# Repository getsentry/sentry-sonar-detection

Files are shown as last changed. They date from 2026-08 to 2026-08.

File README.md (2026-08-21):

<p align="center">
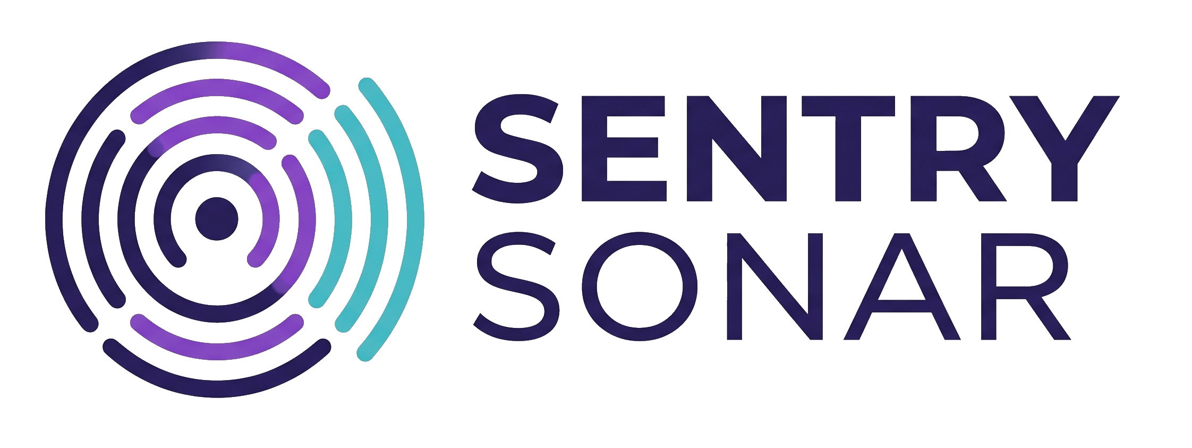
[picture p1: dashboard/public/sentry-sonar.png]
Sentry Sonar
  
</p>

# Sentry Sonar

Real-time meeting-room availability, sensed by radar and shown right on the door.

## What it does

A 24GHz radar sensor in each room detects human presence — *that* a person is
there, never *who* (no cameras, no microphones) — and reports to a Cloudflare
Workers API. Two consumers read that data:

- **E-ink door displays** show **FREE / OCCUPIED** at a glance. Battery-powered,
  they deep-sleep and poll during office hours, running ~1–2 weeks per charge.
- **A web dashboard** gives a live overview of every room, plus how they're used
  over time (utilization, busy hours).

**The outcome:** walk down the hall and see which rooms are free without opening a
calendar or a booking app — and see room-usage trends on the dashboard. Privacy by
design: radar only knows presence, not identity.

## Architecture

```
 Sensor node (Freenove ESP32 + LD2410C radar) ──POST /events──►  Cloudflare
                                                                  Worker (Hono)
 Display node (Waveshare e-paper)  ──GET /rooms/:id──►            + D1
 Dashboard (React SPA)             ──GET /rooms─────►             + static assets
```

Two nodes per room: a mains-powered **sensor node** that senses continuously, and a
battery **display node** that deep-sleeps and polls during office hours. A single
Cloudflare Worker (Hono) on D1 holds current room state plus an append-only event
log **and** serves the dashboard (React SPA) as static assets — same origin, one URL.

## Repo layout

```
firmware/sensor-node/    Freenove + LD2410C radar (PlatformIO)
firmware/display-node/   Waveshare e-paper (GxEPD2 + deep sleep)
api/                     Cloudflare Worker (Hono) + D1 migrations
dashboard/               React SPA (Vite) — served by the Worker as static assets
```

## Docs

- **[SETUP.md](./SETUP.md)** — step-by-step to stand up your own copy end to end
  (Cloudflare backend, dashboard, device tokens, firmware).
- **[PLAN.md](./PLAN.md)** — design, data model, API surface, and the decisions
  behind them.
- **[PRODUCTIONIZING.md](./PRODUCTIONIZING.md)** — current state and what a full
  office-wide rollout would take (IoT Wi-Fi, display power, more pairs, Sentry-
  hosted dashboard, and the operational gaps in between).
- **[api/README.md](./api/README.md)** — API endpoints, deploy & operate, tokens.
- **[firmware/README.md](./firmware/README.md)** — flashing sensors & displays,
  board pinouts, and the battery/power gotchas.

## Status

Hackweek project — 4 rooms, 4 device kits, all provisioned and running.

- App — dashboard + API on one Worker:
  <https://sentry-sonar-api.francesconovy.workers.dev> (the dashboard is at the
  root path; its data only loads from an allowlisted office IP)

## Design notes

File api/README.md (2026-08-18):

# Sentry Sonar — API

Cloudflare Worker ([Hono](https://hono.dev/)) backed by [D1](https://developers.cloudflare.com/d1/).
It ingests presence heartbeats from the sensor nodes and serves room status to
the e-ink displays and the dashboard. See [`../PLAN.md`](../PLAN.md) for the
overall design.

**Deployed at:** <https://sentry-sonar-api.francesconovy.workers.dev>

## Endpoints

| Method | Path | Caller | Auth |
|---|---|---|---|
| `GET` | `/healthz` | anyone | none (health check) |
| `POST` | `/events` | sensor node | device token — **write**, that room |
| `GET` | `/rooms/:id` | display node | device token — **read**, that room |
| `GET` | `/rooms` | dashboard | office IP allowlist |
| `GET` | `/rooms/:id/stats` | dashboard | office IP allowlist |

This same Worker also **serves the dashboard SPA** as static assets (Workers Static
Assets): the API paths above are listed under `run_worker_first` in `wrangler.jsonc`
so they always reach the Worker, and every other path (`/`, `/room-details/:id`,
`/assets/*`, …) is served from the built dashboard, with an `index.html` SPA
fallback. Same origin, so no CORS.

A room's `status` is **derived**, not stored:

- `offline` — no heartbeat within 90s (`OFFLINE_AFTER_SECONDS`), or never seen.
- `in_use` — a recent heartbeat with `occupied: true`.
- `free` — a recent heartbeat with `occupied: false`.

### `GET /healthz` — health

(`/` serves the dashboard SPA, so the health check lives at `/healthz`.)

```console
$ curl https://sentry-sonar-api.francesconovy.workers.dev/healthz
{"service":"sentry-sonar-api","ok":true}
```

### `POST /events` — sensor heartbeat

Send every ~15s. The current room state is upserted; a row is appended to the
event log **only when the occupied state changes** (keeps history compact).

Headers: `Authorization: Bearer <write-token>`, `Content-Type: application/json`

Body:

| field | type | required | notes |
|---|---|---|---|
| `room_id` | string | yes | must match the token's room |
| `occupied` | boolean | yes | radar presence (LD2410C `OUT` pin) |

```console
$ curl -X POST https://sentry-sonar-api.francesconovy.workers.dev/events \
    -H "Authorization: Bearer $TOKEN" -H 'content-type: application/json' \
    -d '{"room_id":"urwald","occupied":true}'
{"ok":true,"room":{"id":"urwald","name":"Urwald","status":"in_use","occupied":true,"lastSeen":1786957010}}
```

Errors: `400` invalid body · `401` bad/missing token · `403` token not allowed
for that room, or a read-only token · `404` unknown room.

### `GET /rooms/:id` — single room (display node)

Tiny payload for the e-ink display. Auth: a **read** (or write) token for that room.

```console
$ curl https://sentry-sonar-api.francesconovy.workers.dev/rooms/urwald -H "Authorization: Bearer $TOKEN"
{"id":"urwald","name":"Urwald","status":"in_use","occupied":true,"lastSeen":1786957010}
```

### `GET /rooms` — all rooms (dashboard)

```console
$ curl https://sentry-sonar-api.francesconovy.workers.dev/rooms
{"now":1786957010,"rooms":[
  {"id":"makava-kingdom","name":"Makava Kingdom","status":"offline","occupied":false,"lastSeen":null},
  {"id":"servus","name":"Servus","status":"offline","occupied":false,"lastSeen":null},
  {"id":"urwald","name":"Urwald","status":"in_use","occupied":true,"lastSeen":1786957010},
  {"id":"oida","name":"Oida","status":"offline","occupied":false,"lastSeen":null}
]}
```

### `GET /rooms/:id/stats` — utilization

Fraction of **office hours** (Mon–Fri 08:00–18:00 Europe/Vienna) the room was
occupied, reconstructed from the event log — nights and weekends are excluded from
both `occupiedSeconds` and `totalSeconds`. Query: `hours` (default `24`, max `720`).

```console
$ curl "https://sentry-sonar-api.francesconovy.workers.dev/rooms/urwald/stats?hours=24"
{"room":"urwald","hours":24,"occupiedSeconds":5400,"totalSeconds":86400,"ratio":0.0625}
```

## Authentication

Two mechanisms for two very different callers (full rationale in `../PLAN.md`).

**Device tokens (sensor + display nodes).** Opaque bearer tokens of the form
`id.secret`, each scoped to one room and one action (`read`/`write`). Only the
SHA-256 hash of the secret is stored in the `api_tokens` table; a `write` token
also satisfies `read`. Sent as `Authorization: Bearer <token>`.

**Office IP allowlist (dashboard).** `GET /rooms` and `/rooms/:id/stats` are
gated by `OFFICE_IP_RANGES` (comma-separated CIDRs, IPv4 + IPv6) matched against
`CF-Connecting-IP`. Fails closed. It's supplied as a **binding**, not committed:
`.dev.vars` locally, a Worker **secret** (`wrangler secret put OFFICE_IP_RANGES`)
in production. For local dev you can instead set `ALLOW_INSECURE_LOCAL=true` in
`.dev.vars` to bypass the gate entirely (never set it in production).

## Local development

```sh
export VOLTA_FEATURE_PNPM=1              # once per shell (see SETUP.md)

cp .dev.vars.example .dev.vars           # local secrets + ALLOW_INSECURE_LOCAL
pnpm --filter api db:migrate:local       # create + migrate the local D1
pnpm --filter api dev                    # wrangler dev on http://localhost:8787
```

Mint a device token and register its hash in the local D1:

```sh
node scripts/mint-token.mjs urwald write
# prints the token once + a `wrangler d1 execute ... --local` INSERT to run
```

Then exercise it:

```sh
TOKEN=<the printed token>
curl -X POST localhost:8787/events -H "Authorization: Bearer $TOKEN" \
     -H 'content-type: application/json' -d '{"room_id":"urwald","occupied":true}'
curl localhost:8787/rooms          # ALLOW_INSECURE_LOCAL bypasses the IP gate
```

## Testing

Tests run inside the Workers runtime with a real local D1
([`@cloudflare/vitest-pool-workers`](https://developers.cloudflare.com/workers/testing/vitest-integration/)):
`ip`/`status` unit tests plus full route + auth + D1 integration tests.

```sh
pnpm --filter api test
```

## Deploy & operate

`wrangler` below is the api workspace's binary — run each from the repo root as
`pnpm --filter api exec wrangler …`, or drop the prefix from inside `api/`.
`deploy` needs `pnpm … run deploy` (it's a reserved pnpm subcommand).

**The Worker also serves the dashboard** (`assets` in `wrangler.jsonc` →
`../dashboard/dist`), so the SPA must be **built before deploying**. The easiest path
is the root **`pnpm run deploy`**, which runs `dashboard build` then `api run deploy`.

### First-time deploy

```sh
wrangler login                                   # authenticate (opens a browser)
wrangler d1 create sentry_sonar                  # → copy the printed database_id
# paste that id into api/wrangler.jsonc:  "database_id": "…"
pnpm --filter api db:migrate                     # apply schema + seed to the remote D1
pnpm run deploy                                       # (from repo root) build dashboard + deploy Worker
wrangler secret put OFFICE_IP_RANGES             # office CIDRs, e.g. 203.0.113.0/29
```

Deployed at <https://sentry-sonar-api.francesconovy.workers.dev>. First deploy on
a fresh account prompts you to pick a free `workers.dev` subdomain.

### Update the Worker (after code changes)

```sh
pnpm --filter api test && pnpm --filter api typecheck
pnpm run deploy   # (from repo root) rebuilds the dashboard + redeploys the Worker
```

(If you only changed the Worker and the dashboard `dist` is current, `pnpm --filter
api run deploy` alone works too.)

### Change a secret / the office allowlist

Secrets apply immediately (a new version, no redeploy). Re-run to change a value:

```sh
wrangler secret put OFFICE_IP_RANGES             # replace the office CIDRs
wrangler secret list
wrangler secret delete OFFICE_IP_RANGES
```

### Change the database schema

Add a **new** migration (never edit an already-applied one), then apply it
local → remote:

```sh
# create api/migrations/0003_<name>.sql
pnpm --filter api db:migrate:local               # apply to the local dev DB
pnpm --filter api db:migrate                     # apply to the remote DB
```

Ad-hoc SQL: `wrangler d1 execute sentry_sonar --remote --command "…"` (use
`--local` for the dev DB).

### Manage device tokens

```sh
# mint (prints the token once + an INSERT statement):
node scripts/mint-token.mjs urwald write
wrangler d1 execute sentry_sonar --remote --command "<the INSERT it printed>"

# list:
wrangler d1 execute sentry_sonar --remote \
  --command "SELECT id, room_id, scope, label, revoked FROM api_tokens;"

# revoke (takes effect immediately):
wrangler d1 execute sentry_sonar --remote \
  --command "UPDATE api_tokens SET revoked=1 WHERE id='ss_xxxx';"
```

### Logs & rollback

```sh
wrangler tail                                    # live request logs
wrangler deployments list                        # deployment history
wrangler rollback                                # revert to the previous version
```

## Layout

```
src/
  index.ts    routes
  auth.ts     device-token + office-IP middleware
  rooms.ts    DB helpers, derived status, heartbeat, utilization
  ip.ts       CIDR matching (IPv4 + IPv6)
  types.ts    shared row/view types
  env.ts      bindings + Hono generics
migrations/   D1 schema (0001) + room seed (0002)
scripts/      mint-token.mjs
test/         vitest (unit + integration)
```

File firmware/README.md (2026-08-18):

# Firmware

ESP32-S3 firmware for the two per-room nodes. Built and flashed with
[PlatformIO](https://platformio.org/) — **not** part of the pnpm workspace.

- **`sensor-node/`** — Freenove ESP32-S3-WROOM-1 + LD2410C radar. Mains-powered,
  always-on; POSTs presence heartbeats to the API (`POST /events`).
- **`display-node/`** — Waveshare ESP32-S3 1.54" e-paper. Battery-powered;
  deep-sleeps and polls `GET /rooms/:id` every 30–60s, redraws on change.

Each device is flashed with its own per-room bearer token and Wi-Fi credentials
(see [../PLAN.md → Authentication](../PLAN.md#authentication--authorization)). The
four rooms are `makava-kingdom`, `urwald`, `servus`, `oida` — use one of these as
the `--room` id below (they're seeded into D1 by the API migrations).

## Prerequisites

Install the PlatformIO **CLI** (`pio`). It is standalone — no VS Code required:

```sh
brew install platformio        # macOS
pio --version                  # confirm it's on PATH
```

First `pio run` for a new board downloads the ESP32 toolchain + Arduino
framework (~100 MB, a minute or two). That's a one-time cost; later builds are
fast.

## Sensor node — wiring

LD2410C 24GHz radar → ESP32-S3-WROOM-1, **3 jumper wires, no soldering, no level
shifter** (the LD2410C's IO is already 3.3V):

| LD2410C pad | → | ESP32-S3 pin |
|---|---|---|
| `VCC` (5V) | → | **5V** (USB-fed rail — *not* 3V3; the radar needs 5V) |
| `GND` | → | **GND** |
| `OUT` / `OT2` | → | **GPIO4** (silkscreen `4`; any free GPIO works if you change the sketch) |

Match the radar pads by their **silkscreen label**, not header position — the
order varies between batches. Mount the radar with its etched-antenna face
toward the room.

## Board & USB port

- **Board id:** `esp32-s3-devkitc-1` (correct generic id for the WROOM-1 module;
  already set in `sensor-node/platformio.ini`).
- The Freenove board has **two USB-C jacks**. Use the **UART** one (CH343
  bridge) — plain `Serial` output flows over it with no extra build flags. The
  other jack is the S3's *native* USB and only shows `Serial` if you compile in
  USB-CDC-on-boot, so it's the wrong choice for these sketches.
- Find the port: `pio device list`. The CH343 shows up as
  `/dev/cu.usbmodem*` with **Hardware ID `VID:PID=1A86:...`** (`1A86` = WCH).
  On macOS it enumerates driver-free.
- The two little buttons near the jacks are **BOOT** (=IO0) and **EN/RST** — not
  port labels.

## Flashing a sensor

`main.cpp` is the production firmware: read the LD2410C OUT pin → `POST /events`.
Each sensor needs a **unique room id + auth token**; the SSID defaults to
`Sentry-Guest` and you enter the WiFi password at flash time.

1. Mint a **write** token for the room and register it in the **remote
   (production) D1** (see [../api/README.md](../api/README.md#manage-device-tokens)):

   ```sh
   node ../../api/scripts/mint-token.mjs urwald write
   # It prints the token once, plus a `wrangler d1 execute … --local` line.
   # Run that line but change --local to --remote, so the hash lands in the
   # production DB the deployed Worker reads (otherwise the device gets 401).
   ```

2. Flash the board with that room + token (you'll be prompted for the WiFi
   password), from `firmware/sensor-node/`:

   ```sh
   ./flash-sensor.sh --room urwald --token 'ss_xxxx.secret' --monitor
   # --monitor opens the serial monitor after flashing so you can watch it boot.
   # options: --wifi-pass <pass>  --ssid <name>  --port /dev/cu.usbmodemXXXX
   ```

The script writes `src/config.gen.h` (gitignored — it holds the token),
compiles, and uploads. Repeat per sensor with its own room + token. Nothing
secret is committed.

## Flashing a display

`display-node/src/main.cpp` is the production firmware: wake from deep sleep,
`GET /rooms/:id`, redraw FREE / OCCUPIED only on change, sleep again. Each
display needs a **read** token for its room (a display can only read; it never
writes state).

1. Mint a **read** token for the room and register it in the **remote
   (production) D1** (see [../api/README.md](../api/README.md#manage-device-tokens)):

   ```sh
   node ../../api/scripts/mint-token.mjs makava-kingdom read
   # run the printed `wrangler d1 execute` line, changing --local to --remote
   ```

2. Flash the board with that room + token (you'll be prompted for the WiFi
   password), from `firmware/display-node/`:

   ```sh
   ./flash-display.sh --room makava-kingdom --token 'ss_xxxx.secret' --monitor
   # options: --wifi-pass <pass>  --ssid <name>  --port /dev/cu.usbmodemXXXX
   ```

   `--ssid` defaults to `Sentry-Guest`; set a per-machine default in
   `display.env` (copy `display.env.example`). The WiFi password is never stored.

Unlike the sensor's dual-jack Freenove, the display board has a **single
native-USB Type-C** port. Find it the same way — `pio device list` — but it
enumerates with **VID `303A:1001`** (Espressif), as `/dev/cu.usbmodem*`. Its two
side buttons are **PWR** and **BOOT** (the one with the "sun" icon).

> **Download mode is required to flash.** The production firmware deep-sleeps, so
> the board's USB port vanishes between wakes and the flasher can't open it. Put it
> in download mode first: unplug USB → hold **BOOT** (the "sun" side button) → plug
> USB back in → release BOOT. Then pass `--port /dev/cu.usbmodemXXXX` explicitly so
> auto-detect doesn't grab an unrelated serial device. See
> [Display board & power gotchas](#display-board--power-gotchas) for the why.

## Display power & polling strategy

The display runs on a small LiPo, so it does as little as possible. The Wi-Fi
wake is essentially the *entire* energy budget, so everything is tuned to minimize
how often the radio turns on.

- **Deep sleep between polls.** Each cycle is a fresh boot: wake → read battery →
  (in active hours) Wi-Fi + `GET /rooms/:id` → redraw **only if the frame
  changed** → deep sleep (~10 µA; e-ink holds its image with no power).
- **Office-hours only.** Polling runs **weekdays 08:00–18:00 local, every 60 s**.
  Nights and weekends the radio never turns on — the board shows an **OFF HOURS**
  message (not a stale FREE/OCCUPIED) and naps (waking at most every ~8 h just to
  re-check the battery) until the next weekday morning. Nobody's in the rooms then,
  so this roughly **triples** battery life.
- **Time without NTP.** The schedule needs a wall clock, which the ESP32 loses in
  deep sleep. Rather than an NTP round-trip, we read the `Date` header off every
  API response (free), track it across sleeps with the wake timer, and re-anchor on
  each daytime poll. Timezone/DST uses the Europe/Vienna POSIX rule.
- **Battery graphic, not a number.** The corner shows a rough fill level (redrawn
  only when the coarse level changes, not every poll); ≤10 % becomes a `!` alert;
  <3 % replaces the room status with a full-screen **RECHARGE ME** (radio kept
  off), so a dying panel never freezes on a misleading FREE/OCCUPIED.

**Expected life ≈ 9–10 days** on the 400 mAh cell (bank on ~1 week to be safe).
Weekday polling dominates, so the active-hours interval is the main lever: 2 min
→ ~2.5 weeks, 5 min → ~5 weeks, trading sign responsiveness for runtime. Tunables
are at the top of `src/main.cpp`: `POLL_SECONDS`, `ACTIVE_START_HOUR`,
`ACTIVE_END_HOUR`, `SKIP_WEEKENDS`.

## Display board & power gotchas

The display is a **Waveshare ESP32-S3-ePaper-1.54** (200×200 B/W, SSD1681 →
`GxEPD2_154_D67`, with an on-board LiPo charger). Everything is wired internally, so
the pin map is fixed and lives at the top of `src/main.cpp`:

| Signal | GPIO | | Signal | GPIO |
|---|---|---|---|---|
| EPD CS / DC | 11 / 10 | | EPD SCK / MOSI | 12 / 13 |
| EPD RST / BUSY | 9 / 8 | | EPD_PWR (panel, **active-LOW**) | 6 |
| VBAT_PWR (battery latch) | 17 | | Battery ADC (ADC1_CH3, ÷2) | 4 |

Three things about this board cost real debugging time — don't relearn them:

- **`VBAT_PWR` (GPIO17) is the battery power latch for the *whole board*, not a
  "measurement divider enable."** HIGH = battery powers the system; **LOW = power
  off** (it's exactly what the vendor demo drives on a long-press-PWR shutdown). The
  firmware asserts it HIGH once at the top of `setup()` and **never drives it LOW**.
  Toggle it — e.g. to "save power while measuring the battery" — and the board dies
  the instant USB is unplugged and browns out mid-refresh on battery, while looking
  perfectly fine on USB (USB powers the board directly, bypassing the latch).
- **Hold GPIO17 through deep sleep.** The ESP32 floats its GPIOs while asleep, so the
  latch would open mid-sleep and the board would never wake on battery. Before
  `esp_deep_sleep_start()` we call `gpio_hold_en(GPIO17)` + `gpio_deep_sleep_hold_en()`
  and release the hold on wake. Without it, USB works but battery deep-sleep is dead.
- **Power button.** On USB the board powers on automatically. On battery, **press
  and hold PWR (~5 s)** to turn it on; a board that's already running hot-swaps to
  battery when USB is pulled, no press needed. A long PWR press powers it off.

### On-device debugging

`src/main.cpp` has a `DEBUG_MODE` switch at the top. Set it to `1` and reflash for a
build identical to production **except** it polls every `DEBUG_POLL_SECONDS` (20 s)
and stamps the current time top-left, redrawing each poll — so you can watch it tick
and confirm it's alive, including on battery. Set back to `0` for production.

## Build, flash, monitor (manual / low-level)

From the node's directory (e.g. `firmware/sensor-node/`):

```sh
pio run                                     # compile only
pio run -t upload                           # compile + flash (auto-detects port)
pio run -t upload --upload-port /dev/cu.usbmodemXXXX   # if auto-detect picks wrong
pio device monitor -b 115200                # serial monitor (Ctrl-] to quit)
```

A good flash ends with `Hash of data verified` → `Hard resetting via RTS pin`
→ `[SUCCESS]`. If it hangs at `Connecting.....`, hold **BOOT**, tap **EN/RST**,
release **BOOT** to force the bootloader, then re-run.

> **Headless/automation note.** `pio device monitor` needs an interactive TTY;
> in a non-interactive shell (CI, a background task) it dies with
> `termios ... Operation not supported by device`. In a real terminal it's fine.
> To read the port from a script instead, use a pyserial reader locked to the
> baud (bundled with PlatformIO):
>
> ```python
> import serial, sys
> s = serial.Serial("/dev/cu.usbmodemXXXX", 115200, timeout=1)
> s.dtr = s.rts = False          # don't reset the board on attach
> while True:
>     line = s.readline()
>     if line: sys.stdout.write(line.decode("utf-8", "replace")); sys.stdout.flush()
> ```
>
> Do **not** use `stty … ; cat /dev/cu.…` — `cat` re-opens the port, macOS
> resets it to 9600, and you get consistent garbage bytes (a wrong-baud read).

## Verifying a flashed sensor

Open the monitor (`--monitor`, or `pio device monitor -b 115200`). Expected on
boot:

   ```
   === Sentry Sonar :: sensor-node ===
   room=urwald  api=https://sentry-sonar-api.francesconovy.workers.dev  radar=GPIO4
   [wifi] connecting to "Sentry-Guest" ...
   [wifi] connected, ip=192.168.x.y
   [http] POST /events occupied=0 -> 200
   ```

1. Move in front of the radar → `[http] POST /events occupied=1 -> 200`. Step
   away → `occupied=0` a few seconds later (24GHz radar reaches ~5m — you often
   have to leave the room, not just lean back). Cross-check with `GET /rooms`.

2. **Prove the read path (rule out a stuck-HIGH pin):** pull the OUT jumper off
   GPIO4 and touch it to a **GND** pin — `occupied` must go to `0` within a
   couple seconds. Move it back to the radar's OUT and presence returns.
   Toggling both ways confirms VCC/GND/OUT and the GPIO read are all correct.

### Troubleshooting

| Symptom | Likely cause |
|---|---|
| Garbage bytes on serial | Wrong baud — use `pio device monitor -b 115200`, not `cat` |
| Stuck `occupied=1`, never clears | You're within radar range (usually fine), or OUT on the wrong pad — run the GND test above |
| Stuck `occupied=0` even in front | OUT not connected to GPIO4, or radar unpowered (VCC on 3V3 instead of 5V) |
| No serial port in `pio device list` | Wrong USB-C jack, charge-only cable, or board not powered — try the other jack |
| Flash hangs at `Connecting.....` | Hold **BOOT**, tap **EN/RST**, release **BOOT**, re-run |
| `[http] … -> 401` or `403` | Token wrong/rotated, unregistered, or scoped to another room — re-mint (see api/README) |
| `[http] … failed` or `[wifi] connect timed out` | Wrong WiFi password/SSID or out of range — reflash with the right `--wifi-pass` |

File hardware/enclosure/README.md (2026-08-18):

# Sensor-node enclosure

3D-printable case for the **sensor node** (ESP32-S3 + LD2410C 24 GHz radar). A
box with a **snap-fit lid**: rounded beads on the lid lip click into pockets in
the body walls, and a thumbnail pry notch pops it back open. The radar antenna
faces the lid, which has a thinned "window" panel so the 24 GHz signal passes
through.

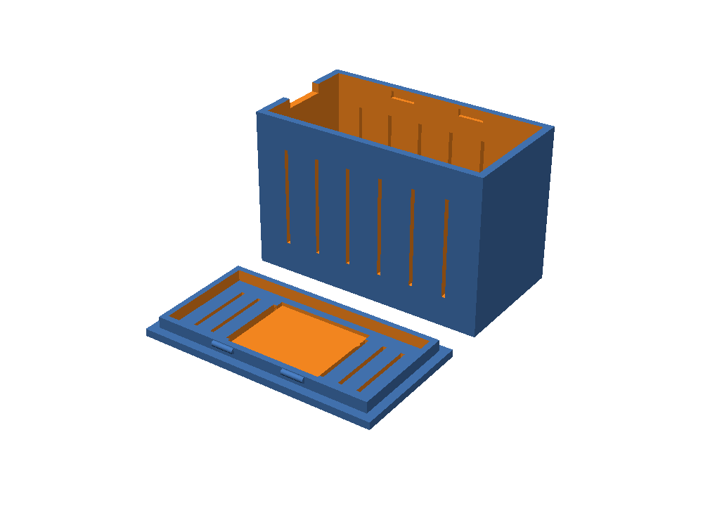
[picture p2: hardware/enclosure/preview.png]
preview


> This is the **sensor-node** enclosure only. There is no display-node enclosure
> yet — the Waveshare display is mounted as-is (see the repo TODO/PLAN).

Everything is generated from one parametric source, `sensor-node-box.scad`.

| File | What it is |
|---|---|
| `sensor-node-box.scad` | The parametric source — edit this, never the STLs |
| `sensor-node-box-body.stl` | Rendered box (print 1×) |
| `sensor-node-box-lid.stl` | Rendered lid (print 1×) |
| `preview.png` | 3/4 render for the docs |
| `render.sh` | Regenerates both STLs + the preview from the `.scad` |

Internal cavity is **60 × 30 × 40 mm** (L×W×H); 2 mm walls give a ~64 × 34 × 44 mm
outer size. There's a 22 mm-wide USB-C slit on one short side (room for two
connectors) and vent slits on the long walls and the lid.

## Printing

- **Filament: PLA or PETG only.** Both are radar-transparent. **Never** use
  carbon-fibre- or metal-filled filament — the 24 GHz radar won't see out.
- Print **body** and **lid** each once. Both are oriented to print flat with no
  supports: the body sits floor-down (open top up), and the lid prints
  plate-down with its locating lip pointing up (flip it to assemble). The radar
  window is thinned from the *inside*, so the outer face stays flush.
- 0.2 mm layers, ~3 perimeters, 15–20 % infill is plenty.

## Regenerating STLs and the preview

Run everything through the helper:

```sh
./render.sh
```

Or invoke OpenSCAD directly (tested with **OpenSCAD 2021.01**,
`brew install --cask openscad`). Render one part per STL:

```sh
openscad -D 'part="body"' -o sensor-node-box-body.stl sensor-node-box.scad
openscad -D 'part="lid"'  -o sensor-node-box-lid.stl  sensor-node-box.scad
```

Preview image (blue body / orange interior via the built-in **Tomorrow** color
scheme; angled so both the body and the lid's top — radar window + snap beads —
are visible):

```sh
openscad -D 'part="all"' --colorscheme=Tomorrow --imgsize=1000,750 \
  --camera=32,39,12,60,0,215,320 -o preview.png sensor-node-box.scad
```

The `--camera` args are `look-at x,y,z` + `rotation x,y,z` + `distance`.

> **Pure-white background.** OpenSCAD has no pure-white built-in scheme
> (`Tomorrow`'s background is `#f8f8f8`) and the app bundle is SIP-protected, so a
> custom scheme can't be dropped in. `render.sh` therefore does a small post-step:
> it floods the flat near-white field to `#ffffff` with Pillow. That's the only
> reason the checked-in `preview.png` is truly white. If Pillow isn't installed
> the render still works — you just keep the `#f8f8f8` background (visually white
> anyway). To get Pillow without touching system Python:
> `python3 -m venv /tmp/v && /tmp/v/bin/pip install Pillow`, then run `render.sh`
> with `/tmp/v/bin` on PATH.

## Tuning the lid fit

The snap-fit is governed by a few parameters near the top of the `.scad`. Two
independent things control how the lid feels:

| Parameter | Default | Controls |
|---|---|---|
| `tol` | `0.3` | Lip clearance — gap per side between lid lip and cavity walls. **Lower = less side-to-side wobble.** |
| `detent_r` | `0.8` | Snap-bead radius. **Higher = firmer click.** |
| `pocket_h` | `2.0` | Catch-pocket height; must clear the bead (`2 × detent_r`) plus a little. |

The retention that actually stops the lid lifting off is the **bead
interference** = `detent_r − tol` (currently `0.8 − 0.3 = 0.5 mm`). Note that
lowering `tol` tightens the lateral fit *and* raises the interference, so the two
levers interact.

- Lid **pops loose / falls off** → raise `detent_r` (try `0.9`), and/or lower
  `tol`. Bump `pocket_h` if `detent_r` grows.
- Lid **too stiff to close, or beads shear** → lower `detent_r` (try `0.7`), or
  raise `tol` back toward `0.4`.
- Lid **rattles** side to side but holds → lower `tol` only.

0.5 mm interference on the 1.6 mm lip wall is firm-but-pry-openable in PLA/PETG
on a typical 0.4 mm nozzle. Printers that run tight may want `detent_r = 0.7`.
Beads and pockets are symmetric in X and Y, so the lid latches whichever way it's
flipped. Re-run `./render.sh` after any change.

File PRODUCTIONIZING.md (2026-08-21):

# Productionizing Sentry Sonar

Sentry Sonar started as a Hackweek project. It **works** — but "works as a demo
in a few rooms" and "a maintained system the office relies on" are different bars.
This document captures the current state and everything we'd (theoretically) need
to do to fully roll it out across the Vienna office and keep it running.

Nothing here is committed work — it's the map from *proof of concept* to
*production*.

## Current state (Aug 2026)

- **4 room pairs deployed** in the Vienna office (`makava-kingdom`, `urwald`,
  `servus`, `oida`), each a mains-powered **sensor node** + a battery **display
  node**. Generally working day to day.
- **Backend** is a single Cloudflare Worker (Hono) + D1, also serving the React
  dashboard as static assets. Live at
  `sentry-sonar-api.francesconovy.workers.dev` (a personal `workers.dev`
  subdomain).
- **Auth** today: per-device bearer tokens (read/write, per room) for the nodes;
  a plain **office-IP allowlist** for the dashboard read routes.
- **Enclosures**: a 3D-printable **sensor** case exists; the **displays ship with
  their own case** and are ready to mount as-is.

It's a working pilot on personal/temporary infrastructure. The gaps below are
what stand between that and "the office depends on it."

## The four big gaps

These are the things actively holding back a real rollout.

### 1. Network — a proper 2.4 GHz IoT Wi-Fi

The ESP32 radios are **2.4 GHz only**, and the office has no suitable 2.4 GHz
network for them. Right now the nodes run off a **phone/router hotspot** — fine
for a pilot, unacceptable for permanent infrastructure (single point of failure,
someone's device, no coverage guarantees).

**What we need:** a dedicated **IoT SSID** that is:

- **2.4 GHz**, WPA2-PSK (or WPA2-Enterprise if IT prefers, but PSK is far simpler
  for headless devices).
- **No captive portal.** Headless ESP32s can't click through a splash page, so
  any network with one is a non-starter. (The existing `Sentry-Guest` network has
  no captive portal and would otherwise work — it's simply **5 GHz**, which the
  radios can't join. The blocker is the band, not the auth.)
- On a **segmented VLAN** with only outbound HTTPS to the Worker allowed — these
  are cheap radar/display boards, so isolate them from the corporate LAN.
- Good AP coverage in every room that gets a pair (the radios are low-power; a
  weak signal is the #1 cause of flaky heartbeats).

**Action:** work with IT/facilities to stand up this SSID, then reflash every
device onto it (Wi-Fi credentials are baked in at flash time today — see
[gap 5, provisioning](#5-provisioning--fleet-management-at-scale)).

### 2. Power — stop babysitting display batteries

Display nodes run on a **400 mAh LiPo** and last **~9–10 days per charge**
(office-hours-only polling already triples what continuous polling would give).
For 4 rooms that's already a weekly recharge chore; across the whole office it's
untenable.

Two options, in order of preference:

- **(Preferred) USB-C wired power.** The display draws almost nothing, so a
  permanent 5 V feed removes the battery problem entirely. The idea: **tap power
  from the meeting-room display's (TV/screen) power source** — most rooms already
  have a mains-powered screen right by the door.
  - This also lets us **drop the battery, charger, and power-latch complexity**
    from the display firmware over time, and poll more frequently (snappier
    FREE/OCCUPIED) since energy is no longer the budget.
- **(Fallback) Much larger battery.** If wired power isn't feasible in some
  rooms, a 2000–3000 mAh cell pushes recharge to ~1.5–2 months. Better, but still
  a recurring manual task, and a larger cell likely won't fit the shipped display
  case. Treat as the exception, not the plan.

**Action:** pick wired-USB-C as the default; validate the "tap behind the screen"
approach in one room; keep a big-battery variant for any room where wiring is
impossible.

### 3. Hardware — build out the remaining rooms

- **More pairs.** Build sensor + display nodes for every remaining meeting room.
  Each pair is: 1× Freenove ESP32-S3 + LD2410C radar (sensor), 1× Waveshare
  1.54" e-paper ESP32-S3 (display), wiring, and power (see gap 2). Capture a
  proper **BOM + per-room cost** so procurement can order in bulk.
- **3D-print the sensor cases.** The parametric case exists
  (`hardware/enclosure/`) — we just need to print body + lid per room (PLA/PETG
  only; radar-transparent). Batch these.
- **Displays need no enclosure work** — they ship with their own case and are
  ready to mount. The only open item is routing the USB-C feed (gap 2) to each
  display's mount point.

**Action:** finalize BOM, order parts, batch-print sensor cases, design the
display case, assemble and provision one pair per remaining room.

### 4. Hosting — move the dashboard to Sentry-owned infrastructure + real auth

Today the whole thing lives on a **personal `workers.dev` subdomain**, and the
dashboard is gated only by an **office-IP allowlist** (fails closed, but IP-based
and brittle — breaks for VPN/remote, and the office's dual-uplink egress
(COLT + Wien Energie) already complicates keeping the allowlist correct).

For production:

- **Move to Sentry-owned hosting** — a Cloudflare account/zone owned by Sentry,
  not an individual, on a **custom domain** (e.g. `sonar.sentry.io` or an
  internal equivalent) instead of `*.workers.dev`. This survives the original
  author leaving and gives us a stable URL.
- **Put the dashboard behind Sentry SSO/OAuth** (Google Workspace / Okta / Sentry
  identity) instead of the IP allowlist. Cloudflare **Access** in front of the
  dashboard routes is the low-effort path — no app code change, real identity, and
  it fixes the remote/VPN gap the IP allowlist has. (Keep the device-token auth
  for the nodes as-is; that part is fine.)
- Decide what stays IP/token-gated (the node-facing `/events` and `/rooms/:id`)
  vs. identity-gated (the human-facing dashboard).

**Action:** provision a Sentry-owned CF account + domain, redeploy there, front
the dashboard with Cloudflare Access, retire the personal subdomain.

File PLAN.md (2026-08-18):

# Sentry Sonar — Implementation Plan

**Sentry Sonar** is a meeting-room occupancy system. Radar sensors detect human
presence in each room and report to a Cloudflare Workers API. Two consumers read
that data: e-ink displays on each room door showing **FREE / OCCUPIED**, and a web
dashboard giving an overview of all rooms and how they're used.

- **Sentry** — stands watch over the room.
- **Sonar** — the radar sensing presence.

## Scope

- **4 meeting rooms:** Makava Kingdom, Urwald, Servus, Oida
  (ids `makava-kingdom`, `urwald`, `servus`, `oida`).
- **4 full room kits** (4 of each device).

## Hardware (per room)

| Component | Role |
|---|---|
| Waveshare ESP32-S3 1.54" E-Paper (200×200, battery) | **Display node** — the sign on the door |
| LD2410C 24GHz radar (presence via GPIO `OUT` pin) | **Presence sensor** |
| Freenove ESP32-S3 Lite | **Sensor node** MCU (hosts the radar) |
| USB-C 25W charger | Mains power for the always-on sensor node |
| Mini breadboard + M-F jumper wires | Wiring radar → ESP32 |

## Architecture

Two nodes per room — each does the job its power source suits:

- **Sensor node** = Freenove ESP32-S3 + LD2410C radar, **mains-powered**.
  Always-on, senses continuously, POSTs presence heartbeats to the API.
- **Display node** = Waveshare e-paper, **battery-powered**. Deep-sleeps and polls
  the API only during **office hours** (weekdays 08:00–18:00 Europe/Vienna, every 60s);
  nights and weekends the radio stays off. Redraws only when the state changes.

Radar presence detection wants to be always on; e-ink wants to sleep and sip
power. Splitting the roles across two devices lets each do what it's good at,
keeps the battery display alive for weeks, and keeps sensing reliable.

*(All-in-one Waveshare — sense + display on one plugged-in device — is kept as a
fallback for a single demo room. Firmware stays modular so it's a small change.)*

```
  MEETING ROOM                          CLOUDFLARE                    CONSUMERS
 ┌─────────────────────┐
 │ Sensor node         │   POST /events    ┌──────────────┐
 │ Freenove + LD2410C  │ ───────────────►  │              │
 │ (mains power)       │   {occupied}      │   Workers    │   GET /rooms/:id
 └─────────────────────┘                   │     API      │ ◄──────────────┐
                                           │   (Hono)     │                │
 ┌─────────────────────┐   GET /rooms/:id  │              │        ┌───────────────┐
 │ Display node        │ ◄──────────────►  │   + D1       │        │ Display node  │
 │ Waveshare e-paper   │   {status}        │  (state +    │        │ (same room)   │
 │ (battery, sleeps)   │                   │   history)   │        └───────────────┘
 └─────────────────────┘                   └──────────────┘
                                                   ▲
                                                   │ GET /rooms
                                           ┌──────────────┐
                                           │ Dashboard    │  overview (served by
                                           │ React + Vite │  the same Worker)
                                           └──────────────┘
```

## Cloudflare stack

- **Workers** — the API **and** the dashboard, from **one** Worker. Hono routes
  the API; the built **React + Vite** SPA is served as **Workers Static Assets**
  (same origin). The dashboard uses **simple polling** (refresh `/rooms` every
  5–10s). Plenty live enough for the demo; no WebSockets.
  *(Originally two deploys — a Worker for the API + Cloudflare Pages for the
  dashboard. Consolidated to one Worker + Static Assets: Pages is in maintenance
  mode, and same-origin removes CORS and unlocks the optional Access-SSO upgrade
  below. API paths are pinned with `run_worker_first`; the SPA's room-detail route
  is `/room-details/:id` so it never collides with the device API's `/rooms/:id`.)*
- **D1** (SQLite) — single data store. Holds current room state **and** an event
  log. The event log powers "how rooms are used" (utilization %, busy hours) on
  the dashboard, so we capture history from day one. No KV / Durable Objects
  needed for this scope.

**Free tier, no custom domain.** Everything runs on one free Cloudflare hostname:
the Worker at `*.workers.dev` serves both the API and the dashboard. This shapes
the auth design (see Authentication) — notably, zone-level WAF rules aren't
available on `workers.dev`, so gating is done in Worker code.

## Observability — Sentry SDK (v11 alpha)

Both the backend (Cloudflare Worker) and the frontend (React dashboard) are
instrumented with the **Sentry SDK**, pinned to the **v11 alpha**. *(This is the
Sentry error-monitoring SDK — unrelated to the project name. Naming collision is
just a happy coincidence.)*

**Important:** v11 is pre-release, so we follow the migration guide **straight
from the repository** — `getsentry/sentry-javascript` `MIGRATION.md` on the
`develop` branch — **not** the published docs, which still describe stable v10.

### Versions & install

v11 alpha is published under the **`next`** dist-tag (there is no `alpha` tag):

```sh
# backend (Cloudflare Worker)
pnpm --filter api add @sentry/cloudflare@next          # 11.0.0-alpha.1

# frontend (React dashboard)
pnpm --filter dashboard add @sentry/react@next         # 11.0.0-alpha.1
```

### Backend — `@sentry/cloudflare` v11 setup notes

- **`wrangler.jsonc` requires `nodejs_compat`** (v11 replaced `nodejs_als`):
  ```diff
  - "compatibility_flags": ["nodejs_als"]
  + "compatibility_flags": ["nodejs_compat"]
  ```
- Wrap the Worker with `withSentry` (or use the Cloudflare Vite plugin, which
  **auto-instruments the Worker by default** in v11).
- `wrapRequestHandler` now lives under the **`@sentry/cloudflare/request`**
  subpath.
- **D1 is auto-instrumented via `env`** — the old `instrumentD1WithSentry` helper
  was removed, so our D1 queries get traced for free.
- DSN supplied via a Worker **secret/env var** (`SENTRY_DSN`).

> Verify each of these against `MIGRATION.md` in the repo at build time — the
> alpha is a moving target.

## Data model

```sql
rooms (
  id          TEXT PRIMARY KEY,   -- e.g. "urwald"
  name        TEXT,               -- "Urwald"
  occupied    INTEGER,            -- 0 / 1
  last_seen   INTEGER,            -- unix seconds of last heartbeat
  updated_at  INTEGER
)

events (                          -- append-only history for analytics
  id          INTEGER PRIMARY KEY AUTOINCREMENT,
  room_id     TEXT,
  occupied    INTEGER,
  created_at  INTEGER
)

api_tokens (                      -- device auth (see Authentication section)
  id          TEXT PRIMARY KEY,   -- public token id (part before the '.'), e.g. "ss_a1b2c3d4"
  token_hash  TEXT NOT NULL,      -- SHA-256 of the secret half; plaintext never stored
  room_id     TEXT,               -- scoped room, or NULL/"*" for all-rooms
  scope       TEXT NOT NULL,      -- 'read' | 'write'
  label       TEXT,               -- "urwald sensor", "urwald display"
  revoked     INTEGER DEFAULT 0,
  created_at  INTEGER
)
```

## Occupancy logic

- Sensor sends a **heartbeat every ~15s** with `occupied: true/false`.
- Server **upserts** the room's current state and **appends an event on state
  change** (keeps the history compact).
- Derived status for consumers:
  - `last_seen` older than **~90s** → **`offline/unknown`** (a dead sensor must
    not show a stale "free").
  - else `occupied` → **OCCUPIED** (API status string `in_use`), else **FREE**.

## API surface

| Method | Route | Caller | Auth | Purpose |
|---|---|---|---|---|
| `GET` | `/healthz` | anyone | none | health check (`/` serves the dashboard) |
| `POST` | `/events` | sensor node | device token — **write**, that room | heartbeat / state |
| `GET` | `/rooms/:id` | display node | device token — **read**, that room | one room's derived status |
| `GET` | `/rooms` | dashboard | **office IP allowlist** (in Worker) | all rooms + status |
| `GET` | `/rooms/:id/stats` | dashboard | **office IP allowlist** (in Worker) | office-hours utilization over time |

See the next section for how each auth type works.

## Authentication & authorization

Two callers with very different trust models, so two mechanisms:

- **IoT devices** are headless and long-lived → **per-room, per-scope bearer
  tokens** we issue and store ourselves.
- **The dashboard** is used by humans and must not be queryable by other
  services/pages → an **office IP allowlist enforced in Worker code** (the default;
  an optional Cloudflare Access SSO upgrade is described later in this section).

### Device tokens (sensor + display nodes)

Opaque random bearer tokens, each scoped to **one room** and **one action**:

| Device | Scope | Room | Can do |
|---|---|---|---|
| urwald sensor | `write` | `urwald` | `POST /events` for urwald only |
| urwald display | `read` | `urwald` | `GET /rooms/urwald` only |
| …×4 rooms | | | 8 tokens total |

**How it works:**

1. Mint a token of the form `id.secret`: `id` is random (`ss_` + 8 hex chars, e.g.
   `ss_a1b2c3d4`) and `secret` is ~24 random bytes (base64url). The `id` does **not**
   encode the room — room scoping lives in the `room_id` column.
2. Store only the **SHA-256 hash** of the secret in `api_tokens` (plaintext never
   hits the DB). Flash the full `id.secret` into each device's config (build-time define).
3. A Hono middleware on device routes: read `Authorization: Bearer <token>`,
   split on the `.` to get the id, look up the row by id, `sha256(secret) === token_hash`,
   check `revoked = 0`, then enforce **scope** (read vs. write) and that
   `room_id` matches the `:id` / body room. Reject → `401`/`403`.

**Why this over signed JWTs:** with only 8 devices, a tiny D1 lookup table is
less code, instantly **revocable** (flip `revoked`), and trivial to reason about.
No key rotation or token-expiry machinery to build. Enforcing "this exact room,
this one action" is a two-field check.

### Dashboard auth — office IP allowlist (free tier, no custom domain)

We're staying on a **free Cloudflare hostname** with **no custom domain** — one
Worker at `*.workers.dev` serves both the dashboard and the API (same origin). That
rules out some options and shapes the design:

- **WAF custom rules are zone-only → not available on `workers.dev`.** So the IP
  gate can't be a firewall rule; it must be enforced **in Worker code**.
- **Cloudflare Access _does_ now work on `workers.dev`** (Aug 2026 Worker-level
  Access), but it's **all-or-nothing per Worker**. Because the dashboard and API
  are same-origin on one Worker, Access would be a clean fit for remote SSO — see
  the optional upgrade below. For the hackweek we default to the IP allowlist.

**Default (recommended for the hackweek): IP allowlist enforced in the Worker.**
The dashboard is low-sensitivity, glanceable, and consumed **in the office**
(wall-mounted screens, people on the floor), so the office network is a natural
boundary. Read routes (`GET /rooms`, `/rooms/:id/stats`) check the caller's IP
in code; everything else is rejected:

```js
// Hono middleware on dashboard read routes
const ip = c.req.header('CF-Connecting-IP')      // set by Cloudflare, trustworthy
if (!inOfficeRanges(ip)) return c.json({ error: 'forbidden' }, 403)
```

- No login, no custom domain, works 100% on free tier.
- The dashboard static shell can stay public — it's useless without data, and
  the data is gated at the Worker.
- Trade-off: **no remote access** to the dashboard. For an in-office occupancy
  board that's acceptable (arguably a feature).

**Prepare for multiple office egress IPs.** Offices commonly present several
static egress IPs (multiple WAN links, NAT pools, sites), plus IPv6. Model the
allowlist as a **list of CIDRs**, not a single address, in a Worker env var so
adding a site is a one-line change:

The Worker reads it as a **comma-separated** string of CIDRs (IPv4 + IPv6), set as
a secret — e.g. `203.0.113.0/29` (site A WAN pool), `198.51.100.42/32` (site B),
`2001:db8:1234::/48` (office IPv6):

```sh
wrangler secret put OFFICE_IP_RANGES
# value: 203.0.113.0/29,198.51.100.42/32,2001:db8:1234::/48
```

**Optional upgrade — add remote SSO without a custom domain.** The dashboard is
already served **same-origin from the Worker** (Workers Static Assets), so the only
remaining step for remote access is to enable **Worker-level Cloudflare Access**
with a policy of **Bypass office IPs + Allow `@company.com`** → office is login-free,
remote gets SSO. Catch: Access is **all-or-nothing per Worker**, and the device
routes (token auth) can't do SSO — enabling Access on this Worker would lock the
sensors/displays out. So first split **device ingestion onto a separate Worker**
(no Access), then apply Access to the dashboard Worker. Validate identity via
`ctx.access.getIdentity()`. More moving parts — only if remote access is needed.

**Why not a shared read token in the frontend?** Anything shipped in browser JS
is copyable, so a bearer token there isn't "reliable auth." The IP gate ties data
access to the office network — satisfying "other services/pages cannot easily
query the rooms data."

**Caveats:** IP matching is coarse — anyone on an allowlisted network (incl.
**guest WiFi** sharing the same egress IP) is treated as in-office; acceptable
for occupancy data. Confirm the office IPs are truly static and keep the CIDR
list current.

### Provisioning & hygiene

- Seed the 8 device tokens with a small admin script / `wrangler d1 execute`.
- All traffic is HTTPS (Workers default) — tokens never travel in cleartext.
- Rotate/revoke by updating the `api_tokens` row; re-flash the affected device.
- Keep the Sentry DSN and any secrets in Worker **secrets**, not in the repo.

## Radar integration

The LD2410C's **GPIO `OUT` pin** goes HIGH on presence — a single `digitalRead()`
is all the sensor node needs. The system only cares about **occupied true/false**,
so we deliberately skip the UART path (distance, moving/stationary targets,
sensitivity config): no radar library, no extra wiring beyond `VCC` / `GND` /
`OUT`.

## Sensor networking (WiFi)

The ESP32-S3 radio is **2.4 GHz only** — there is no 5 GHz support and no
software upgrade for it (only the separate ESP32-C5 chip is dual-band). This
constrains which network the sensors can join:

- The office **`Sentry-Guest` SSID is 5 GHz-only**, so the sensors **cannot use
  it**. Nearby 2.4 GHz coverage is also weak (~−88 dBm at the test spot).
- **Testing:** a mobile hotspot (`FN-Hotspot`) with 2.4 GHz forced on.
- **Production:** the rooms need a **2.4 GHz PSK SSID** — ideally a dedicated
  IoT/guest network **without a captive portal** (ask IT), or a local 2.4 GHz AP
  per floor. WPA2 or WPA2/WPA3-mixed; WPA3-Personal also works on the S3, so the
  band — not the security type — is the only hard requirement.

The SSID is set per-flash via `flash-sensor.sh --ssid`; the **WiFi password is
entered at flash time and never stored** (no file/env fallback).

## Repository layout

```
sentry-sonar/
├─ firmware/
│  ├─ sensor-node/     # Freenove + LD2410C  (PlatformIO / Arduino)
│  └─ display-node/    # Waveshare e-paper   (GxEPD2 + deep sleep)
├─ api/                # Cloudflare Worker (Hono) + D1 schema/migrations
├─ dashboard/          # React SPA (Vite), served by the Worker
└─ PLAN.md
```

## Implementation phases

1. **API + D1 spine (mock data).** Get `/events`, `/rooms`, `/rooms/:id` working
   and curl-testable. Seed the 4 rooms. Fastest path to a real endpoint the rest
   can build against.
2. **Sensor node.** Freenove + radar OUT pin → WiFi → POST heartbeats. Watch real
   state land in D1.
3. **Display node.** Waveshare polls `/rooms/:id`, renders FREE / OCCUPIED,
   deep-sleeps between polls. Polls **office-hours only** (weekdays 08:00–18:00
   local @ 60s; nights & weekends the radio stays off and it shows an **OFF HOURS**
   message instead of a stale status), taking wall-clock time from the API's `Date`
   response header. Battery shown as a graphic (no number): `!` alert ≤10%,
   full-screen **RECHARGE ME** <3%. See
   [firmware/README.md](firmware/README.md#display-power--polling-strategy).
4. **Dashboard.** React + Vite grid of 4 room cards, polling `/rooms`.
5. **Polish.** Utilization stats, offline-detection UI, battery tuning, partial
   e-ink refresh, provisioning the 4 kits (room IDs, WiFi creds, tokens).

Building the cloud spine first lets firmware and dashboard progress in parallel
against a real, working API.

## Confirmed decisions

A short log of settled choices — the rationale for each is in the sections above.

- Two nodes per room (sensor + display), not all-in-one. ✅
- Display polls **office-hours only** (weekdays 08:00–18:00 Europe/Vienna @ 60s;
  radio off nights/weekends); wall-clock from the API `Date` header, no NTP;
  ~9–10 days per charge. ✅
- Display battery needs two board fixes — `VBAT_PWR`/GPIO17 is the power latch (HIGH
  at boot, never LOW), held through deep sleep. See
  [firmware/README.md](firmware/README.md#display-board--power-gotchas). ✅
- Dashboard: React + Vite, simple polling (no WebSockets). ✅
- Data store: **D1 only** (current state + event log). ✅
- Radar via GPIO `OUT` pin — occupied true/false only, no UART/distance. ✅
- Sentry SDK, **v11 alpha** (`next` tag), set up per the repo's `MIGRATION.md`. ✅
- **One Worker** at `*.workers.dev` serves the API + dashboard (Static Assets), same
  origin — free tier, no custom domain (was Worker + Pages; Pages is deprecated). ✅
- Auth: per-room, per-scope **device bearer tokens** (D1) for IoT; **office IP
  allowlist** (CIDR list) in Worker code for the dashboard routes. ✅

## Open items

- Provision a **2.4 GHz PSK SSID** (no captive portal) for the sensors in the
  real rooms — `Sentry-Guest` is 5 GHz-only and the ESP32-S3 is 2.4 GHz-only.
  Plus the WiFi credentials strategy for the 4 sensor + 4 display nodes.
- Collect the office **static egress IPs** (all sites/WAN links + IPv6) for the
  CIDR allowlist; confirm they're truly static.
- Physical mounting of sensor node + display at each door.
- Sentry projects + DSNs (one combined vs. separate backend/frontend projects).

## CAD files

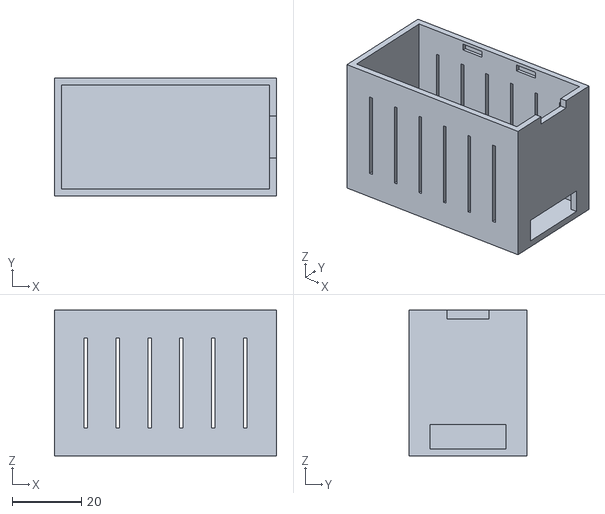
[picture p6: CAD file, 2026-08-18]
hardware/enclosure/sensor-node-box-body.stl
64.0 x 34.0 x 42.0

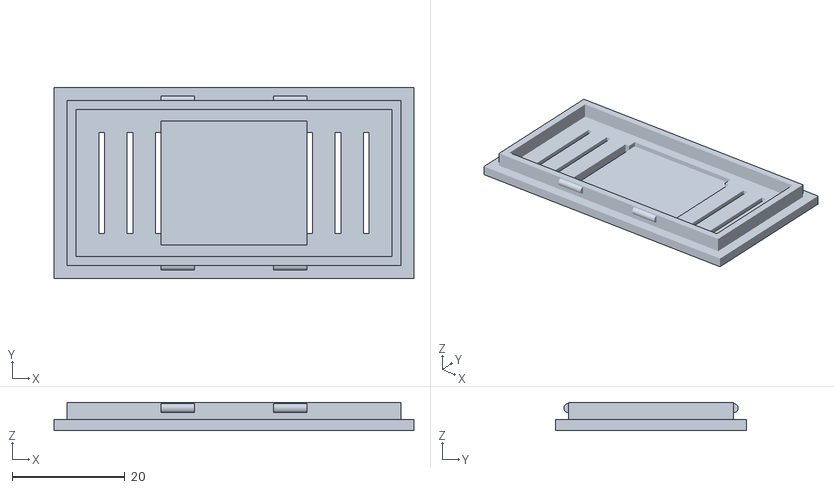
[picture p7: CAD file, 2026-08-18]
hardware/enclosure/sensor-node-box-lid.stl
64.0 x 34.0 x 5.00

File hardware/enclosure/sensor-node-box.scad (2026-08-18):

// Sentry Sonar — sensor-node enclosure
// INTERNAL cavity 60 (L) x 30 (W) x 40 (H) mm. Body + snap-fit lid
// (rounded detents on the lip click into pockets in the body walls; a pry
// notch in the rim pops it open by thumbnail).
// Outer size is derived from the wall thickness (see below).
// Vent slits on the long walls and the lid; a 5 mm-tall USB-C opening on one
// short side. Print in PLA or PETG (radar-transparent) — never carbon-fibre /
// metal-filled filament, or the 24 GHz radar won't see out.
//
// Render one part at a time:
//   openscad -D 'part="body"' -o sensor-node-box-body.stl sensor-node-box.scad
//   openscad -D 'part="lid"'  -o sensor-node-box-lid.stl  sensor-node-box.scad

part = "all";      // "body" | "lid" | "all" (all = both, laid out for preview)

/* ---- Internal (usable) cavity, mm ---- */
IL = 60;           // internal length (X)
IW = 30;           // internal width  (Y)
IH = 40;           // internal height (Z), floor to lid underside

/* ---- Shell ---- */
wall = 2;          // side wall thickness
floor_t = 2;       // floor thickness
lid_t = 2;         // lid plate thickness
tol = 0.3;         // fit clearance for the lid lip (tighter = less lateral wobble)

/* ---- USB-C opening (on the +X short side) ---- */
usb_w = 22;        // width  (Y) — room for two USB-C connectors side by side
usb_h = 7;         // height (Z) — the USB-C slit (~0.7 cm)
usb_z0 = 0;        // flush with the inner floor (no gap)

/* ---- Vent slits on the two long walls (+/-Y) ---- */
vent_w = 1.0;
vent_h = 26;
vent_n = 6;
vent_end_margin = 9;   // keep slits clear of the short ends

/* ---- Vent slits on the lid (two clusters flanking the radar window) ---- */
lid_vent_w = 1.0;
lid_vent_len = 18;
lid_vent_per_end = 3;
lid_vent_gap = 5;

/* ---- Snap-fit detents (lip beads <-> body wall pockets) + pry notch ---- */
// Two rounded beads on each long lip face click into shallow pockets in the
// body's inner walls. Interference at the pass point = detent_r - tol, so tune
// the snap feel by nudging detent_r (0.8 @ tol 0.3 -> 0.5 mm = firm, pry-open;
// drop to 0.7 if too stiff, raise to 0.9 if it still pops loose). Positions are
// symmetric in X and Y, so the lid latches whichever way it is flipped.
detent_r     = 0.8;        // bead radius = protrusion from the lip face
detent_len   = 6;         // bead length along the wall
detent_below = 2.0;        // bead centre this far below the lid seam
detent_xs    = [22, 42];   // X centres (symmetric about L/2); sit above the vent slits
pocket_depth = 1.0;        // how deep the catch pocket bites into the 2 mm wall
pocket_h     = 2.0;        // pocket height (bead dia 1.6 + clearance)
pocket_over  = 1.0;        // pocket longer than the bead (total) for easy seating

pry_notch    = true;       // scallop in the rim to lift the lid by thumbnail
pry_notch_w  = 12;         // width along Y
pry_notch_d  = 2.5;        // depth down from the rim

/* ---- Radar window on the lid (thinned panel; radar antenna faces the lid) ---- */
win_l = 26;        // window length (X)
win_w = 22;        // window width  (Y)
window_t = 1;      // remaining thickness over the window (radar-transparent)

$fn = 48;

/* ---- Derived outer dimensions ---- */
L = IL + 2 * wall;         // outer length -> 64
W = IW + 2 * wall;         // outer width  -> 34
body_h = floor_t + IH;     // outer body height (open top) -> 42
// total outer height = body_h + lid_t -> 44

// ---------------------------------------------------------------- body
module long_wall_vents() {
    step = (L - 2 * vent_end_margin) / (vent_n - 1);
    z0 = (body_h - vent_h) / 2;
    for (i = [0 : vent_n - 1]) {
        x = vent_end_margin + i * step - vent_w / 2;
        translate([x, -1, z0]) cube([vent_w, wall + 2, vent_h]);            // -Y
        translate([x, W - wall - 1, z0]) cube([vent_w, wall + 2, vent_h]);  // +Y
    }
}

// Catch pockets in the two long inner walls; the lid beads snap in below the
// pocket's top edge (which forms the pull-out catch). zc matches the lid bead:
//   body-frame z  = body_h - detent_below
//   lid-frame z   = lid_t  + detent_below   (the lid prints flipped)
// so assembled they meet at z = body_h + lid_t - detent_below.
module detent_pockets() {
    zc = body_h - detent_below;
    plen = detent_len + pocket_over;
    for (x = detent_xs) {
        translate([x - plen / 2, wall - pocket_depth, zc - pocket_h / 2])
            cube([plen, pocket_depth + 0.02, pocket_h]);              // -Y wall
        translate([x - plen / 2, W - wall - 0.01, zc - pocket_h / 2])
            cube([plen, pocket_depth + 0.02, pocket_h]);              // +Y wall
    }
}

// Thumbnail scallop in the +X rim (opposite corner from any cabling), just
// outboard of the lip, so a nail slips under the lid edge to pop it.
module pry_cut() {
    translate([L - wall - 0.5, (W - pry_notch_w) / 2, body_h - pry_notch_d])
        cube([wall + 1, pry_notch_w, pry_notch_d + 1]);
}

module body() {
    difference() {
        cube([L, W, body_h]);
        // hollow interior (open top): exactly IL x IW, full height and above
        translate([wall, wall, floor_t])
            cube([IL, IW, body_h]);
        // USB-C opening on the +X short side
        translate([L - wall - 1, (W - usb_w) / 2, floor_t + usb_z0])
            cube([wall + 2, usb_w, usb_h]);
        long_wall_vents();
        detent_pockets();
        if (pry_notch) pry_cut();
    }
}

// ---------------------------------------------------------------- lid
// Vent clusters near each short end (slots run in Y), leaving the centre clear
// for the radar window.
module lid_vents() {
    span = (lid_vent_per_end - 1) * lid_vent_gap + lid_vent_w;
    for (side = [0, 1]) {
        base_x = (side == 0) ? 8 : L - 8 - span;
        for (i = [0 : lid_vent_per_end - 1]) {
            x = base_x + i * lid_vent_gap;
            translate([x, (W - lid_vent_len) / 2, -1])
                cube([lid_vent_w, lid_vent_len, lid_t + 2]);
        }
    }
}

// Radar window: thin the central panel from the interior side so the outer face
// stays flush (and prints support-free). Leaves `window_t` of solid plastic.
module radar_window() {
    translate([(L - win_l) / 2, (W - win_w) / 2, window_t])
        cube([win_l, win_w, lid_t - window_t + 0.01]);
}

// Rounded snap beads on the two long lip faces. The lip outer face sits at
// (wall + tol) from the box centre line, so each bead protrudes past the wall
// inner face by (detent_r - tol) -> the interference that has to be pushed over.
module detent_beads() {
    zc = lid_t + detent_below;
    yA = wall + tol;           // -Y lip face
    yB = W - wall - tol;       // +Y lip face
    for (x = detent_xs) {
        translate([x - detent_len / 2, yA, zc]) rotate([0, 90, 0]) cylinder(h = detent_len, r = detent_r);
        translate([x - detent_len / 2, yB, zc]) rotate([0, 90, 0]) cylinder(h = detent_len, r = detent_r);
    }
}

module lid() {
    // Printed plate-down with the locating lip pointing UP; flip to assemble.
    lip_out_l = IL - 2 * tol;
    lip_out_w = IW - 2 * tol;
    lip_wall = 1.6;
    lip_h = 3;
    difference() {
        union() {
            cube([L, W, lid_t]);
            translate([(L - lip_out_l) / 2, (W - lip_out_w) / 2, lid_t])
                difference() {
                    cube([lip_out_l, lip_out_w, lip_h]);
                    translate([lip_wall, lip_wall, -1])
                        cube([lip_out_l - 2 * lip_wall, lip_out_w - 2 * lip_wall, lip_h + 2]);
                }
            detent_beads();
        }
        lid_vents();
        radar_window();
    }
}

// ---------------------------------------------------------------- layout
if (part == "body" || part == "all") body();
if (part == "lid"  || part == "all") translate([0, W + 10, 0]) lid();

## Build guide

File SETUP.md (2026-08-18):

# Setup — replicate Sentry Sonar

End-to-end instructions to stand up your own Sentry Sonar somewhere else — the
Cloudflare backend, the dashboard, device tokens, and firmware on each sensor and
display. This file is the ordered how-to; the deep detail for each piece lives in
[api/README.md](./api/README.md) (backend + tokens) and
[firmware/README.md](./firmware/README.md) (flashing, wiring, gotchas), and the
design rationale is in [PLAN.md](./PLAN.md).

## Prerequisites

- **Node + pnpm** via [Volta](https://volta.sh/) (Node 26 + pnpm 10, pinned in
  `package.json`).
- A **Cloudflare account** with Workers + D1. `wrangler` ships with the api
  workspace — the commands below run it from `api/` as `pnpm exec wrangler …`.
- **[PlatformIO CLI](https://platformio.org/)** (`pio`) for firmware.
- **Hardware per room:** Freenove ESP32-S3 + LD2410C 24GHz radar (sensor node);
  Waveshare ESP32-S3-ePaper-1.54 (display node). Full list in
  [PLAN.md → Hardware](./PLAN.md#hardware-per-room).

## 1. Clone & install

```sh
curl https://get.volta.sh | bash          # if you don't have Volta
git clone https://github.com/getsentry/sentry-sonar-detection.git && cd sentry-sonar-detection
export VOLTA_FEATURE_PNPM=1               # add to your shell profile (e.g. ~/.zshrc) to persist
pnpm install                              # installs the api + dashboard workspaces
```

## 2. Cloudflare — one Worker serves the API **and** the dashboard

Details in [api/README.md → Deploy & operate](./api/README.md#deploy--operate).

```sh
# Set up D1 (from api/):
cd api
pnpm exec wrangler login                        # authenticate (opens a browser)
pnpm exec wrangler d1 create sentry_sonar       # → copy the printed database_id
# paste that id into api/wrangler.jsonc:  "database_id": "…"
pnpm db:migrate                                 # schema + seeds the 4 rooms (remote D1)

# Build the dashboard + deploy the Worker together (from the repo root):
cd ..
pnpm run deploy                                     # = dashboard build, then api deploy

# Secrets (from api/):
cd api
pnpm exec wrangler secret put OFFICE_IP_RANGES  # office CIDRs, e.g. 203.0.113.0/29
pnpm exec wrangler secret put SENTRY_DSN        # optional — error/trace monitoring
```

`pnpm run deploy` (root) builds the dashboard into `dashboard/dist` and deploys the
Worker, which bundles that as its static assets. The migration seeds the rooms (no
separate seed step). First deploy on a fresh account prompts for a free
`workers.dev` subdomain — the **API and dashboard share that one URL**; note it for
the firmware config. The dashboard's data routes stay gated to `OFFICE_IP_RANGES`.

## 3. Device tokens

Every room needs **two** tokens: a **write** token for its sensor and a **read**
token for its display. The seeded room ids are `makava-kingdom`, `urwald`, `servus`,
`oida` — use one as `<room-id>`. Mint each (prints the token once + an `INSERT`),
then register the hash in D1. See
[api/README.md → Manage device tokens](./api/README.md#manage-device-tokens).

```sh
cd api
node scripts/mint-token.mjs <room-id> write     # sensor  → save the token
node scripts/mint-token.mjs <room-id> read      # display → save the token
# For EACH: run the printed `wrangler d1 execute` line, changing --local to
# --remote so the hash lands in the production DB the deployed Worker reads.
```

The plaintext token is shown **once** — save it, you'll flash it into the device
next. Only its SHA-256 hash is stored, so a lost token means re-minting.

## 4. Flash the firmware

Full wiring, download-mode, and power notes in
[firmware/README.md](./firmware/README.md).

```sh
# Sensor (write token; prompts for the WiFi password, never stored):
cd firmware/sensor-node
./flash-sensor.sh --room <room-id> --token 'ss_xxx.secret' --ssid <SSID> --monitor

# Display (read token; the board deep-sleeps, so put it in DOWNLOAD MODE first —
# see the firmware README — then pass its port explicitly):
cd firmware/display-node
./flash-display.sh --room <room-id> --token 'ss_xxx.secret' --ssid <SSID> \
  --port /dev/cu.usbmodemXXXX --monitor
```

Repeat per room.

> **Point the firmware at *your* Worker.** The flash scripts default `SS_API_BASE`
> to the reference deployment (`sentry-sonar-api.francesconovy.workers.dev`), so a
> verbatim flash talks to *that* backend, not yours. Set it to the `workers.dev`
> URL from step 2 before flashing — export `SS_API_BASE=…`, or set it in
> `sensor.env` / `display.env` (copy the `*.env.example`).

## Local development

```sh
cp api/.dev.vars.example api/.dev.vars
pnpm --filter api db:migrate:local        # create + migrate the local dev D1
pnpm dev:api                              # Worker at http://localhost:8787
pnpm dev:dashboard                        # Vite dev server (proxies /rooms, /events)
```

Use the **Vite dev server** (`pnpm dev:dashboard`, with HMR) for frontend work — it
proxies API calls to the local Worker. `pnpm dev:api` (`wrangler dev`) also serves
`dashboard/dist` as assets, so if you want to exercise the single-Worker path
locally, run `pnpm --filter dashboard build` first.

Local dashboard data shows up only because `api/.dev.vars.example` sets
`ALLOW_INSECURE_LOCAL="true"`, which bypasses the office-IP gate. Keep it for local
dev; **never set it in production** (there the gate uses `OFFICE_IP_RANGES`).

## Test & typecheck

```sh
pnpm test
pnpm typecheck
```

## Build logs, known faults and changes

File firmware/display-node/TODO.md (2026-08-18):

# Display-node — open items

## Battery operation — RESOLVED

Battery/deep-sleep operation works. Two board-specific fixes were needed, both now
in `src/main.cpp` and documented in
[README.md → Display board & power gotchas](../README.md#display-board--power-gotchas):

1. **`VBAT_PWR` (GPIO17) is the battery power latch** — assert HIGH at boot, never
   drive it LOW. (We were driving it LOW after every battery read, i.e. running the
   board's shutdown command, which killed battery operation while looking fine on USB.)
2. **Hold GPIO17 through deep sleep** (`gpio_hold_en` + `gpio_deep_sleep_hold_en`),
   or the latch opens mid-sleep and the board never wakes on battery.

## Optional / nice-to-have

- **Skip DHCP with a self-learning static IP** (Wi-Fi power). Every wake currently
  re-runs DHCP (~0.3–0.8 s of radio-on time). Cache the DHCP-assigned IP / gateway /
  subnet / DNS in RTC on the first connect, then `WiFi.config(...)` with them before
  `WiFi.begin` on later wakes to bring the link up with no DHCP round-trip; clear the
  cache and fall back to DHCP if a static connect fails. ~10–20 % less Wi-Fi energy
  → roughly +1–2 days on the ~9–10 day life, no responsiveness cost. The bigger cost
  (TLS handshake) needs session resumption across deep-sleep, which the Arduino
  `WiFiClientSecure` wrapper doesn't expose cleanly — not worth it.
- **Bulk cap (470–1000 µF) across the battery pads** — not required (the cells run
  the board fine now), but would add margin for a weak/aged cell against the
  Wi-Fi + refresh current spikes.
- **Partial e-ink refresh** for the routine updates — lower current and no
  full-screen flash than the current full refresh. Needs base-image management
  across deep-sleep cold-boots; deferred since full refresh works.

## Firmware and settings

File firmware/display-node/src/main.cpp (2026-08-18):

// Sentry Sonar — display node firmware.
//
// A battery-powered e-ink door sign. Every POLL_SECONDS it wakes from deep
// sleep, checks the battery, fetches its room's status from the API
// (GET /rooms/:id, READ token), and redraws ONLY when something changed — then
// goes straight back to deep sleep. E-ink holds the last image with zero power,
// so between wakes the whole board draws ~10 µA.
//
// Per-display identity (room id + READ token) and the WiFi password are injected
// at flash time by flash-display.sh, which writes src/config.gen.h (gitignored).
// See ../README.md → "Flashing a display".
//
// Battery behaviour (e-ink keeps its last frame even when the board dies, so we
// must never leave a stale FREE/OCCUPIED on a dead panel):
//   > 10%  → corner battery graphic shows a rough fill level
//   ≤ 10%  → corner graphic becomes a "!" recharge alert
//   <  3%  → skip the network entirely and show a full-screen RECHARGE ME, so the
//            final persisted image is unambiguous; sleep longer to eke out charge.
//
// Board pin map is FIXED (integrated board, wired internally) — from Waveshare's
// ESP32-S3-ePaper-1.54 demo:
//   EPD:  CS=11  DC=10  SCK=12  MOSI=13  RST=9  BUSY=8   (SSD1681, 200x200 B/W)
//   PWR:  EPD_PWR=6  (ACTIVE-LOW: drive LOW to power the panel)
//   BATT: VBAT_PWR=17 (drive HIGH to enable divider)  ADC=GPIO4 (ADC1_CH3, /2)

#include <Arduino.h>
#include <SPI.h>
#include <WiFi.h>
#include <WiFiClientSecure.h>
#include <HTTPClient.h>
#include <esp_sleep.h>
#include <driver/gpio.h>  // gpio_hold_en/dis — keep VBAT latch high through deep sleep
#include <time.h>
#include <GxEPD2_BW.h>
#include <Fonts/FreeSansBold18pt7b.h>
#include <Fonts/FreeSans9pt7b.h>

#include "logo.h"  // LOGO_BITS / LOGO_W / LOGO_H, generated from the icon PNG

// Per-display config, generated by flash-display.sh (gitignored). Fallbacks keep
// a bare `pio run` compiling without it.
#if __has_include("config.gen.h")
#include "config.gen.h"
#endif
#ifndef DISPLAY_ROOM_ID
#define DISPLAY_ROOM_ID "unset-room"
#endif
#ifndef DISPLAY_TOKEN
#define DISPLAY_TOKEN ""
#endif
#ifndef WIFI_SSID
#define WIFI_SSID "Sentry-Guest"
#endif
#ifndef WIFI_PASS
#define WIFI_PASS ""
#endif
#ifndef API_BASE
#define API_BASE "https://sentry-sonar-api.francesconovy.workers.dev"
#endif

// ---- Board pins (fixed by the integrated board) --------------------------
constexpr int PIN_EPD_CS   = 11;
constexpr int PIN_EPD_DC   = 10;
constexpr int PIN_EPD_SCK  = 12;
constexpr int PIN_EPD_MOSI = 13;
constexpr int PIN_EPD_RST  = 9;
constexpr int PIN_EPD_BUSY = 8;
constexpr int PIN_EPD_PWR  = 6;   // active-LOW panel power gate
constexpr int PIN_VBAT_PWR = 17;  // BATTERY POWER LATCH: HIGH=battery on, LOW=power OFF.
                                  // Assert HIGH at boot, NEVER drive LOW (that shuts the
                                  // board off on battery — it's the demo's power-off cmd).
constexpr int PIN_BAT_ADC  = 4;   // ADC1_CH3, reads Vbat/2

constexpr int SCREEN_W = 200;
constexpr int SCREEN_H = 200;

// ---- Tunables ------------------------------------------------------------
constexpr uint32_t POLL_SECONDS    = 60;    // normal wake cadence (active hours)
constexpr uint32_t CRITICAL_SLEEP  = 300;   // slower polling once critically low
constexpr int      BATT_DEAD_PCT   = 3;     // below this: RECHARGE ME, no network
constexpr int      BATT_ALERT_PCT  = 10;    // below this: "!" on the corner glyph
constexpr uint32_t WIFI_TIMEOUT_MS = 8000;  // per connect attempt
constexpr int      BATT_EMPTY_MV   = 3300;  // LiPo: 3.30V -> 0%
constexpr int      BATT_FULL_MV    = 4200;  // LiPo: 4.20V -> 100%

// ---- Active-hours schedule (office hours only, to save battery) -----------
// Poll only on weekdays between these local hours; outside that, skip Wi-Fi
// entirely and nap until the next active window. Time comes from the API's
// `Date` response header (see fetchScreen), tracked across deep sleep.
constexpr int      ACTIVE_START_HOUR = 8;      // 08:00 local
constexpr int      ACTIVE_END_HOUR   = 18;     // 18:00 local (exclusive)
constexpr bool     SKIP_WEEKENDS     = true;   // no polling Sat/Sun
// Cap on a single off-hours nap. Off-hours wakes are nearly free (no radio), so
// this barely affects battery — it just sets how often we re-check the battery
// and bound clock drift overnight/weekends. The morning resume is always
// scheduled exactly to ACTIVE_START_HOUR regardless of this cap.
constexpr uint32_t NIGHT_CAP_SECONDS = 8 * 3600;  // 8h
// Europe/Vienna, incl. EU DST rule (CET/CEST).
static const char* TZ_VIENNA = "CET-1CEST,M3.5.0,M10.5.0/3";

// ---- Debug mode ----------------------------------------------------------
// 1 = bring-up/debugging: NO deep sleep (board stays awake so USB serial stays
// 1 = debug: identical to production EXCEPT it polls every DEBUG_POLL_SECONDS
//     (instead of POLL_SECONDS), redraws every poll, and stamps the poll time in
//     the top-left corner — so you can watch it tick. Everything else (deep sleep,
//     office-hours schedule, all screens) is the same as production.
// 0 = production.
#define DEBUG_MODE 0
constexpr uint32_t DEBUG_POLL_SECONDS = 20;

#if DEBUG_MODE
#  define DEBUG_TAG "  [DEBUG]"
#else
#  define DEBUG_TAG ""
#endif

// What the panel is currently showing. Used both to pick a layout and as the
// redraw dedup key (together with the battery bucket), so unchanged wakes draw
// nothing at all.
enum Screen : uint8_t {
  SCR_FREE, SCR_OCCUPIED, SCR_UNKNOWN, SCR_NOWIFI, SCR_NOAPI, SCR_RECHARGE,
  SCR_OFFHOURS, SCR_INVALID = 255,
};

// State that must survive deep sleep (RTC memory persists; RAM does not).
RTC_DATA_ATTR uint32_t rtcMagic;       // cold-boot marker
RTC_DATA_ATTR uint8_t  rtcScreen;      // last Screen drawn
RTC_DATA_ATTR int8_t   rtcBattBucket;  // last battery bucket drawn
RTC_DATA_ATTR uint8_t  rtcBssid[6];    // cached AP for fast reconnect
RTC_DATA_ATTR int32_t  rtcChannel;
RTC_DATA_ATTR bool     rtcHaveAp;
RTC_DATA_ATTR bool     rtcTimeValid;   // do we have a wall-clock estimate?
RTC_DATA_ATTR int64_t  rtcEpoch;       // estimated UTC epoch at THIS wake
constexpr uint32_t RTC_MAGIC = 0x50D1A202;  // bump on state/enum changes -> clean re-init

// SSD1681 200x200 B/W panel.
GxEPD2_BW<GxEPD2_154_D67, GxEPD2_154_D67::HEIGHT> display(
    GxEPD2_154_D67(PIN_EPD_CS, PIN_EPD_DC, PIN_EPD_RST, PIN_EPD_BUSY));

static time_t g_epoch = 0;  // last known epoch, for the debug clock stamp

// ---- Battery -------------------------------------------------------------
// VBAT_PWR (GPIO17) is the battery power latch — asserted HIGH once in setup()
// and kept HIGH. It must NOT be toggled here: driving it LOW powers the board
// off on battery (it's the demo's shutdown command). We only read the ADC.
uint32_t readBatteryMv() {
  analogSetPinAttenuation(PIN_BAT_ADC, ADC_11db);  // ~0..3.3V range
  uint32_t acc = 0;
  for (int i = 0; i < 16; i++) acc += analogReadMilliVolts(PIN_BAT_ADC);
  return (acc / 16) * 2;                           // undo the 1/2 divider
}

int batteryPercent(uint32_t mv) {
  long pct = (long)((int)mv - BATT_EMPTY_MV) * 100 / (BATT_FULL_MV - BATT_EMPTY_MV);
  if (pct < 0) pct = 0;
  if (pct > 100) pct = 100;
  return (int)pct;
}

// Coarse level; a redraw is only forced when this changes.
int batteryBucket(int pct) {
  if (pct < BATT_DEAD_PCT)  return 0;   // dead / recharge
  if (pct <= BATT_ALERT_PCT) return 1;  // alert
  if (pct <= 30) return 2;
  if (pct <= 55) return 3;
  if (pct <= 80) return 4;
  return 5;                             // full
}

// ---- Time & schedule -----------------------------------------------------
// Convert a UTC broken-down time to epoch seconds without touching TZ (Howard
// Hinnant's civil-from-days). The system TZ stays Europe/Vienna for local
// decisions, so we can't use mktime() here (it assumes local time).
static long daysFromCivil(int y, unsigned m, unsigned d) {
  y -= m <= 2;
  const long era = (y >= 0 ? y : y - 399) / 400;
  const unsigned yoe = (unsigned)(y - era * 400);
  const unsigned doy = (153 * (m + (m > 2 ? -3 : 9)) + 2) / 5 + d - 1;
  const unsigned doe = yoe * 365 + yoe / 4 - yoe / 100 + doy;
  return era * 146097 + (long)doe - 719468;
}
static time_t utcTmToEpoch(const struct tm& t) {
  long days = daysFromCivil(t.tm_year + 1900, t.tm_mon + 1, t.tm_mday);
  return (time_t)days * 86400 + t.tm_hour * 3600 + t.tm_min * 60 + t.tm_sec;
}

// Is `lt` (local time) inside the active polling window?
static bool isActiveLocal(const struct tm& lt) {
  if (SKIP_WEEKENDS && (lt.tm_wday == 0 || lt.tm_wday == 6)) return false;  // Sun/Sat
  return lt.tm_hour >= ACTIVE_START_HOUR && lt.tm_hour < ACTIVE_END_HOUR;
}

// Epoch of the next active-window start (next weekday at ACTIVE_START_HOUR),
// strictly after `now`. Uses local time + mktime so DST is handled.
static time_t nextActiveStart(time_t now) {
  for (int add = 0; add < 9; add++) {
    struct tm t;
    localtime_r(&now, &t);
    t.tm_mday += add;  // mktime normalizes overflow into the next month
    t.tm_hour = ACTIVE_START_HOUR;
    t.tm_min = 0;
    t.tm_sec = 0;
    t.tm_isdst = -1;
    time_t cand = mktime(&t);
    struct tm c;
    localtime_r(&cand, &c);
    bool weekend = (c.tm_wday == 0 || c.tm_wday == 6);
    if (cand > now && (!SKIP_WEEKENDS || !weekend)) return cand;
  }
  return now + NIGHT_CAP_SECONDS;  // shouldn't happen
}

// ---- WiFi ----------------------------------------------------------------
static void cacheAp() {
  const uint8_t* b = WiFi.BSSID();
  if (b) memcpy(rtcBssid, b, 6);
  rtcChannel = WiFi.channel();
  rtcHaveAp = true;
}

static bool waitForConnect() {
  uint32_t start = millis();
  while (WiFi.status() != WL_CONNECTED && millis() - start < WIFI_TIMEOUT_MS) delay(100);
  return WiFi.status() == WL_CONNECTED;
}

// Connect, preferring the cached BSSID+channel (skips the scan → much less time
// with the radio on). Falls back to a normal connect if the hint is stale.
bool connectWifi() {
  WiFi.persistent(false);
  WiFi.mode(WIFI_STA);
  WiFi.setTxPower(WIFI_POWER_8_5dBm);  // lower TX peak -> gentler on a weak battery
  if (rtcHaveAp) {
    WiFi.begin(WIFI_SSID, WIFI_PASS, rtcChannel, rtcBssid);
    if (waitForConnect()) { cacheAp(); return true; }
    WiFi.disconnect(true);
    delay(50);
  }
  WiFi.begin(WIFI_SSID, WIFI_PASS);
  if (waitForConnect()) { cacheAp(); return true; }
  rtcHaveAp = false;
  return false;
}

// Fetch the room status and map it to a Screen (incl. the failure screens).
// On a successful response, also parses the `Date` header into `epochOut` and
// sets `gotTime` — our free wall-clock source for the active-hours schedule.
Screen fetchScreen(bool& gotTime, time_t& epochOut) {
  if (!connectWifi()) {
    Serial.println("[wifi] connect failed");
    return SCR_NOWIFI;
  }
  Serial.printf("[wifi] connected, ip=%s\n", WiFi.localIP().toString().c_str());

  WiFiClientSecure client;
  client.setInsecure();  // skip cert validation — hackweek LAN use

  HTTPClient http;
  String url = String(API_BASE) + "/rooms/" + DISPLAY_ROOM_ID;
  if (!http.begin(client, url)) return SCR_NOAPI;
  http.addHeader("Authorization", String("Bearer ") + DISPLAY_TOKEN);
  const char* wanted[] = {"Date"};
  http.collectHeaders(wanted, 1);

  int code = http.GET();
  if (code != 200) {
    Serial.printf("[http] GET /rooms/%s -> %d\n", DISPLAY_ROOM_ID, code);
    http.end();
    return SCR_NOAPI;
  }
  // Server time, e.g. "Wed, 21 Oct 2026 07:28:00 GMT" — always UTC.
  String date = http.header("Date");
  struct tm dt = {};
  if (date.length() && strptime(date.c_str(), "%a, %d %b %Y %H:%M:%S", &dt)) {
    epochOut = utcTmToEpoch(dt);
    gotTime = true;
  }
  String body = http.getString();
  http.end();
  Serial.printf("[http] GET /rooms/%s -> 200 %s\n", DISPLAY_ROOM_ID, body.c_str());

  int i = body.indexOf("\"status\":\"");
  if (i < 0) return SCR_NOAPI;
  i += 10;
  int j = body.indexOf('"', i);
  if (j < 0) return SCR_NOAPI;
  String s = body.substring(i, j);
  if (s == "free")    return SCR_FREE;
  if (s == "in_use")  return SCR_OCCUPIED;
  if (s == "offline") return SCR_UNKNOWN;
  return SCR_NOAPI;
}

// ---- Drawing -------------------------------------------------------------
void drawCentered(const char* s, int16_t baselineY, const GFXfont* font) {
  display.setFont(font);
  int16_t bx, by;
  uint16_t bw, bh;
  display.getTextBounds(s, 0, 0, &bx, &by, &bw, &bh);
  display.setCursor((SCREEN_W - (int16_t)bw) / 2 - bx, baselineY);
  display.print(s);
}

void drawCenteredSmall(const char* s, int16_t topY) {
  display.setFont(NULL);  // built-in 5x7
  display.setTextSize(1);
  int16_t bx, by;
  uint16_t bw, bh;
  display.getTextBounds(s, 0, 0, &bx, &by, &bw, &bh);
  display.setCursor((SCREEN_W - (int16_t)bw) / 2 - bx, topY);
  display.print(s);
}

// A battery glyph at (x0,y0) sized w×h. Draws a "!" when pct <= alertPct,
// otherwise a fill proportional to pct. Scales for both the corner and the big
// recharge screen.
void drawBattery(int x0, int y0, int w, int h, int pct, int alertPct) {
  const bool big = w >= 30;
  const int t = big ? 2 : 1;               // outline thickness
  const int nubW = big ? 4 : 2, nubH = h / 2;
  for (int k = 0; k < t; k++)
    display.drawRect(x0 + k, y0 + k, w - 2 * k, h - 2 * k, GxEPD_BLACK);
  display.fillRect(x0 + w, y0 + (h - nubH) / 2, nubW, nubH, GxEPD_BLACK);

  if (pct <= alertPct) {                    // exclamation mark
    const int sw = big ? 6 : 2;             // stroke width
    const int cx = x0 + w / 2 - sw / 2;
    const int top = y0 + h / 5;
    const int stemH = big ? h * 9 / 20 : h - 5;
    const int gap = big ? 4 : 1;
    const int dotH = big ? 5 : 1;
    display.fillRect(cx, top, sw, stemH, GxEPD_BLACK);
    display.fillRect(cx, top + stemH + gap, sw, dotH, GxEPD_BLACK);
  } else {                                  // fill level
    const int inner = w - 2 * t;
    const int fill = inner * pct / 100;
    if (fill > 0) display.fillRect(x0 + t, y0 + t, fill, h - 2 * t, GxEPD_BLACK);
  }
}

static const char* headlineFor(Screen s) {
  switch (s) {
    case SCR_FREE:     return "FREE";
    case SCR_OCCUPIED: return "OCCUPIED";
    case SCR_UNKNOWN:  return "UNKNOWN";
    case SCR_NOWIFI:
    case SCR_NOAPI:    return "OFFLINE";
    case SCR_OFFHOURS: return "OFF HOURS";
    default:           return "";
  }
}

static const char* subtitleFor(Screen s) {
  switch (s) {
    case SCR_UNKNOWN:  return "sensor offline";
    case SCR_NOWIFI:   return "no Wi-Fi";
    case SCR_NOAPI:    return "no signal";
    case SCR_OFFHOURS: return "monitoring paused";
    default:           return nullptr;
  }
}

static const char* screenName(Screen s) {
  switch (s) {
    case SCR_FREE:     return "FREE";
    case SCR_OCCUPIED: return "OCCUPIED";
    case SCR_UNKNOWN:  return "UNKNOWN";
    case SCR_NOWIFI:   return "NOWIFI";
    case SCR_NOAPI:    return "NOAPI";
    case SCR_RECHARGE: return "RECHARGE";
    case SCR_OFFHOURS: return "OFFHOURS";
    default:           return "INVALID";
  }
}

void powerPanel(bool on) {
  pinMode(PIN_EPD_PWR, OUTPUT);
  digitalWrite(PIN_EPD_PWR, on ? LOW : HIGH);  // active-LOW
}

void render(Screen scr, int pct) {
  powerPanel(true);
  delay(100);
  SPI.begin(PIN_EPD_SCK, /*MISO=*/-1, PIN_EPD_MOSI, PIN_EPD_CS);
  display.init(115200);
  display.setRotation(0);
  display.setTextColor(GxEPD_BLACK);
  display.setFullWindow();
  display.firstPage();
  do {
    display.fillScreen(GxEPD_WHITE);
#if DEBUG_MODE
    {  // debug: stamp the poll time top-left so you can watch it tick each poll
      struct tm lt;
      localtime_r(&g_epoch, &lt);
      char t[16];
      strftime(t, sizeof(t), "%H:%M:%S", &lt);
      display.setFont(NULL);
      display.setTextSize(1);
      display.setCursor(2, 2);
      display.print(t);
    }
#endif
    if (scr == SCR_RECHARGE) {
      // Dedicated dying-battery screen — no room status at all.
      drawBattery(/*x0=*/(SCREEN_W - 76 - 4) / 2, /*y0=*/26, /*w=*/76, /*h=*/36,
                  /*pct=*/0, /*alertPct=*/100);
      drawCentered("RECHARGE", 118, &FreeSansBold18pt7b);
      drawCentered("ME", 158, &FreeSansBold18pt7b);
      drawCenteredSmall("plug in to charge", 178);
    } else {
      const int logoX = (SCREEN_W - LOGO_W) / 2, logoY = 12;
      display.drawBitmap(logoX, logoY, LOGO_BITS, LOGO_W, LOGO_H, GxEPD_BLACK);
      drawCentered("SENTRY SONAR", logoY + LOGO_H + 20, &FreeSans9pt7b);
      drawCentered(headlineFor(scr), 178, &FreeSansBold18pt7b);
      const char* sub = subtitleFor(scr);
      if (sub) drawCenteredSmall(sub, 186);
      drawBattery(/*x0=*/SCREEN_W - 3 - 2 - 14, /*y0=*/4, /*w=*/14, /*h=*/8,
                  pct, BATT_ALERT_PCT);
    }
  } while (display.nextPage());
  display.hibernate();
  powerPanel(false);  // cut the panel rail; e-ink keeps the image
}

// ---- Lifecycle -----------------------------------------------------------
void deepSleep(uint32_t seconds) {
  WiFi.disconnect(true);
  WiFi.mode(WIFI_OFF);
  Serial.printf("deep sleep %us\n", seconds);
  Serial.flush();
  // Latch the battery-power pin (GPIO17) HIGH through deep sleep — otherwise the
  // ESP32 floats its GPIOs while sleeping, the VBAT latch opens, and the board
  // powers off on battery and never wakes.
  gpio_hold_en((gpio_num_t)PIN_VBAT_PWR);
  gpio_deep_sleep_hold_en();
  esp_sleep_enable_timer_wakeup((uint64_t)seconds * 1000000ULL);
  esp_deep_sleep_start();
}

// One poll/draw cycle. Returns how many seconds to wait before the next one.
uint32_t runCycle(bool cold) {
  uint32_t mv = readBatteryMv();
  int pct = batteryPercent(mv);
  int bucket = batteryBucket(pct);
  Serial.printf("battery: %u mV (~%d%%) bucket=%d\n", mv, pct, bucket);

  // 1) Critical battery overrides everything: no radio, show RECHARGE.
  if (pct < BATT_DEAD_PCT) {
    Serial.println("battery critical — skipping network");
    if (cold || rtcScreen != SCR_RECHARGE) {
      render(SCR_RECHARGE, pct);
      rtcScreen = SCR_RECHARGE;
      rtcBattBucket = (int8_t)bucket;
    }
    return CRITICAL_SLEEP;
  }

  // 2) Are we inside active hours? Needs a clock estimate; if we have none yet
  //    (cold boot), we poll anyway to acquire the time from the Date header.
  bool haveTime = rtcTimeValid;
  time_t nowEpoch = haveTime ? (time_t)rtcEpoch : 0;
  bool activeNow = true;
  if (haveTime) {
    struct tm lt;
    localtime_r(&nowEpoch, &lt);
    char b[32];
    strftime(b, sizeof(b), "%a %H:%M", &lt);
    activeNow = isActiveLocal(lt);
    Serial.printf("local: %s  active=%d\n", b, activeNow);
  } else {
    Serial.println("no clock yet — polling to acquire time");
  }

  // 3) Poll when active (or still time-less); else show OFF HOURS, radio off.
  Screen desired;
  if (activeNow || !haveTime) {
    bool gotTime = false;
    time_t netEpoch = 0;
    desired = fetchScreen(gotTime, netEpoch);
    if (gotTime) {
      nowEpoch = netEpoch;
      haveTime = true;
      rtcTimeValid = true;
      // Polled only to learn the time; if it's off-hours, show OFF HOURS.
      struct tm lt;
      localtime_r(&nowEpoch, &lt);
      if (!isActiveLocal(lt)) desired = SCR_OFFHOURS;
    }
  } else {
    desired = SCR_OFFHOURS;
  }
  Serial.printf("screen=%s\n", screenName(desired));

  // Network is done — power the radio down BEFORE the e-ink refresh so the Wi-Fi
  // and panel current spikes don't overlap and brown out a battery-powered board.
  WiFi.disconnect(true);
  WiFi.mode(WIFI_OFF);
  delay(50);  // let the rail settle after the radio drops

  g_epoch = nowEpoch;  // for the debug clock stamp

  // 4) Redraw when the frame changed (or always, in debug).
  bool forceDraw = false;
#if DEBUG_MODE
  forceDraw = true;
#endif
  if (cold || forceDraw || desired != rtcScreen || bucket != rtcBattBucket) {
    Serial.println("draw");
    render(desired, pct);
    rtcScreen = desired;
    rtcBattBucket = (int8_t)bucket;
  } else {
    Serial.println("skip (no redraw)");
  }

  // 5) How long until the next poll: the active-hours interval, else nap until
  //    the next active window (capped so battery is still checked periodically).
#if DEBUG_MODE
  const uint32_t pollInterval = DEBUG_POLL_SECONDS;
#else
  const uint32_t pollInterval = POLL_SECONDS;
#endif
  uint32_t sleepS = pollInterval;
  if (haveTime) {
    struct tm lt;
    localtime_r(&nowEpoch, &lt);
    if (!isActiveLocal(lt)) {
      time_t wake = nextActiveStart(nowEpoch);
      long secs = (long)(wake - nowEpoch);
      if (secs < (long)pollInterval) secs = pollInterval;
      sleepS = (uint32_t)(secs < (long)NIGHT_CAP_SECONDS ? secs : NIGHT_CAP_SECONDS);
      struct tm wl;
      localtime_r(&wake, &wl);
      char b[32];
      strftime(b, sizeof(b), "%a %H:%M", &wl);
      Serial.printf("off-hours — next active %s (nap %us)\n", b, sleepS);
    }
  }

  // Pre-advance the clock estimate to the next wake (re-anchored on next poll).
  if (haveTime) rtcEpoch = (int64_t)nowEpoch + (millis() / 1000) + sleepS;
  return sleepS;
}
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
void loop() {
  // Unused — setup() always ends in deep sleep, which restarts at setup().
}

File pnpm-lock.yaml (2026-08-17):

lockfileVersion: '9.0'

settings:
  autoInstallPeers: true
  excludeLinksFromLockfile: false

importers:

  .: {}

  api:
    dependencies:
      '@sentry/cloudflare':
        specifier: 11.0.0-alpha.1
        version: 11.0.0-alpha.1(@cloudflare/workers-types@5.20260817.1)(wrangler@4.123.0(@cloudflare/workers-types@5.20260817.1))
      hono:
        specifier: ^4
        version: 4.13.2
    devDependencies:
      '@cloudflare/vitest-pool-workers':
        specifier: ^0.21.3
        version: 0.21.3(@cloudflare/workers-types@5.20260817.1)(@vitest/runner@4.1.10)(@vitest/snapshot@4.1.10)(vitest@4.1.10(@opentelemetry/api@1.9.1)(jsdom@30.0.1)(vite@6.4.3))
      '@cloudflare/workers-types':
        specifier: ^5
        version: 5.20260817.1
      typescript:
        specifier: ^5
        version: 5.9.3
      vitest:
        specifier: ^4.1.10
        version: 4.1.10(@opentelemetry/api@1.9.1)(jsdom@30.0.1)(vite@6.4.3)
      wrangler:
        specifier: ^4
        version: 4.123.0(@cloudflare/workers-types@5.20260817.1)

  dashboard:
    dependencies:
      '@sentry/react':
        specifier: 11.0.0-alpha.1
        version: 11.0.0-alpha.1(react@19.2.8)
      react:
        specifier: ^19
        version: 19.2.8
      react-dom:
        specifier: ^19
        version: 19.2.8(react@19.2.8)
      react-router:
        specifier: ^8.3.0
        version: 8.3.0(react-dom@19.2.8(react@19.2.8))(react@19.2.8)
    devDependencies:
      '@testing-library/react':
        specifier: ^16.3.2
        version: 16.3.2(@testing-library/dom@10.4.1)(@types/react-dom@19.2.4(@types/react@19.2.18))(@types/react@19.2.18)(react-dom@19.2.8(react@19.2.8))(react@19.2.8)
      '@types/react':
        specifier: ^19
        version: 19.2.18
      '@types/react-dom':
        specifier: ^19
        version: 19.2.4(@types/react@19.2.18)
      '@vitejs/plugin-react':
        specifier: ^4
        version: 4.7.0(vite@6.4.3)
      jsdom:
        specifier: ^30.0.1
        version: 30.0.1
      typescript:
        specifier: ^5
        version: 5.9.3
      vite:
        specifier: ^6
        version: 6.4.3
      vitest:
        specifier: ^4.1.10
        version: 4.1.10(@opentelemetry/api@1.9.1)(jsdom@30.0.1)(vite@6.4.3)

packages:

  '@asamuzakjp/css-color@6.0.7':
    resolution: {integrity: sha512-vC/bk1Lz7Tn/EfU9/apOTBk80/8dyGyWMowPoV1tJ52muDGsDqt2HPT2klrFUiY60MQmQv9q8yIht15JnBgDGw==}
    engines: {node: ^22.13.0 || >=24.0.0}

  '@asamuzakjp/dom-selector@8.3.2':
    resolution: {integrity: sha512-93Z1N+BQNXysodoicpOIyNh2drHfz/CTf9nnT0FEx72GJcIiwgydD7tGAr78j41LsYn3hlRn+LdGPuBLn1Bl8Q==}
    engines: {node: ^22.13.0 || >=24.0.0}

  '@babel/code-frame@7.29.7':
    resolution: {integrity: sha512-Aup7aUOfpbAUg2ROOJN6Iw5f9DMBlzu0mIkm/malLQFN/YQgO48wCj0Kxa3sEHJvPVFg7siR+qRInwXd2qhQKw==}
    engines: {node: '>=6.9.0'}

  '@babel/compat-data@7.29.7':
    resolution: {integrity: sha512-locTkQyKvwIEgBzVrn8693ebc97F2U8ZHjbXwDXJ5Fn2TCpNwTlKcaKLkdHop5c/icOFE7qt7Q9JC5hnKNa6Gg==}
    engines: {node: '>=6.9.0'}

  '@babel/core@7.29.7':
    resolution: {integrity: sha512-RgHBCvtjbOK2gXSNBNIkNoEc9qoVEtau3hj8gEqKQuL3HZAibKarWFEI3Lfm6EYKkLalOh8eSrj9b+ch9H/VBA==}
    engines: {node: '>=6.9.0'}

  '@babel/generator@7.29.8':
    resolution: {integrity: sha512-gZbepsdh3WDtgZKWL+vTPh71LSBrm/Y4/QDZBVCcYfmeTEEuoOYwlSy+G1StfJg+/Zy550u/3TATbm7qDbbMtg==}
    engines: {node: '>=6.9.0'}

  '@babel/helper-compilation-targets@7.29.7':
    resolution: {integrity: sha512-wem6WaBj4NaVYVdNhLPPVacES6ZJ+KBBfSkTMD3YZxbP3rm3Di85tJU5ljaUNhaOynt+Aj0xruhYuzQBt8n71g==}
    engines: {node: '>=6.9.0'}

  '@babel/helper-globals@7.29.7':
    resolution: {integrity: sha512-3nQVUAtvkKH9zahfWgw96Jc/uFOmjACE1kQz82E2lqWmHBgjzbNlsC22nuQTfahmWeQtTq5nQ/4Nnd2A1wj4zA==}
    engines: {node: '>=6.9.0'}

  '@babel/helper-module-imports@7.29.7':
    resolution: {integrity: sha512-ejHwrQQYcm9xnTivShn2IDOlIzInN34AXskvq9QicvCtEzq1Vzclu/tKF8Jq1Cg8JG2GL6/EmjgsCT7lXepE3g==}
    engines: {node: '>=6.9.0'}

  '@babel/helper-module-transforms@7.29.7':
    resolution: {integrity: sha512-UPUVSyXbOh627KiCIGQSgwWzGeBKLkaJ9PJEdrngIwMSzxLR4jS4+f1f1jb7VzBbg8nFLaYotvVPFCTqdrmTAg==}
    engines: {node: '>=6.9.0'}
    peerDependencies:
      '@babel/core': ^7.0.0

  '@babel/helper-plugin-utils@7.29.7':
    resolution: {integrity: sha512-G7sHYigPY17oO5SYWnfD/0MTBwVR781S/JI643e/JhUYgVgWE/61SoW3NH9KWUKyKq5LVh3npif99Wkt6j86Jw==}
    engines: {node: '>=6.9.0'}

  '@babel/helper-string-parser@7.29.7':
    resolution: {integrity: sha512-Pb5ijPrZ89GDH8223L4UP8i6QApWxs04RbPQJTeWDV0/keR2E36MeKnyr6LYmUUvqRRI+Iv87SuF1W6ErINzYw==}
    engines: {node: '>=6.9.0'}

  '@babel/helper-validator-identifier@7.29.7':
    resolution: {integrity: sha512-qehxGkRj55h/ff8EMaJ+cYhyaKlHIxqYDn682wQD7RNp9UujOQsHog2uS0r2vzr4pW+sXf90NeeayjcNaX3fFg==}
    engines: {node: '>=6.9.0'}
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

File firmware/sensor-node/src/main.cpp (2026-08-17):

// Sentry Sonar — sensor node firmware.
//
// Reads human presence from the LD2410C radar's OUT pin and reports it to the
// Sentry Sonar API (POST /events) over WiFi. Sends a heartbeat on every state
// change and at least every HEARTBEAT_MS so the server can detect a dead node.
//
// Per-sensor identity (room id + auth token) and the WiFi password are injected
// at flash time by flash-sensor.sh, which writes src/config.gen.h (gitignored).
// See ../README.md → "Flashing a sensor".
//
// Wiring (3 jumpers, no soldering, no level shifter):
//   LD2410C VCC -> ESP32-S3 5V   (USB-fed rail, NOT 3V3)
//   LD2410C GND -> ESP32-S3 GND
//   LD2410C OUT -> ESP32-S3 GPIO4

#include <Arduino.h>
#include <WiFi.h>
#include <WiFiClientSecure.h>
#include <HTTPClient.h>
#include <string.h>

// Per-sensor config, generated by flash-sensor.sh (gitignored). Fallbacks below
// keep a bare `pio run` compiling without it.
#if __has_include("config.gen.h")
#include "config.gen.h"
#endif

#ifndef SENSOR_ROOM_ID
#define SENSOR_ROOM_ID "unset-room"
#endif
#ifndef SENSOR_TOKEN
#define SENSOR_TOKEN ""
#endif
#ifndef WIFI_SSID
#define WIFI_SSID "Sentry-Guest"
#endif
#ifndef WIFI_PASS
#define WIFI_PASS ""
#endif
#ifndef API_BASE
#define API_BASE "https://sentry-sonar-api.francesconovy.workers.dev"
#endif

// Tunables.
constexpr uint8_t  RADAR_OUT_PIN         = 4;      // LD2410C OUT -> GPIO4
constexpr uint32_t HEARTBEAT_MS          = 15000;  // max time between reports
constexpr uint32_t DEBOUNCE_MS           = 500;    // presence must be stable this long
constexpr uint32_t POLL_MS               = 100;    // radar poll cadence
constexpr uint32_t MIN_ATTEMPT_MS        = 3000;   // throttle POST retries
constexpr uint32_t WIFI_CONNECT_TIMEOUT  = 20000;

static bool     reported       = false;  // last state confirmed to the server
static bool     candidate      = false;  // last raw radar read
static uint32_t candidateSince = 0;      // when `candidate` last changed
static uint32_t lastSend       = 0;      // millis of last successful POST
static uint32_t lastAttempt    = 0;      // millis of last POST attempt
static bool     forceSend      = true;   // force the first report

const char *wifiStatusStr(wl_status_t s) {
  switch (s) {
    case WL_IDLE_STATUS:   return "IDLE";
    case WL_NO_SSID_AVAIL: return "NO_SSID_AVAIL (SSID not seen — 5GHz-only, hidden, or out of range)";
    case WL_SCAN_COMPLETED:return "SCAN_COMPLETED";
    case WL_CONNECTED:     return "CONNECTED";
    case WL_CONNECT_FAILED:return "CONNECT_FAILED (wrong password, or captive-portal/enterprise auth)";
    case WL_CONNECTION_LOST:return "CONNECTION_LOST";
    case WL_DISCONNECTED:  return "DISCONNECTED";
    default:               return "UNKNOWN";
  }
}

// The ESP32-S3 radio is 2.4GHz only, so this lists every 2.4GHz network in
// range. If the target SSID isn't here, it's 5GHz / hidden / out of range.
// Reset radio state first — a scan run mid-association returns nothing.
void scanNetworks() {
  Serial.println("[wifi] scanning 2.4GHz networks...");
  WiFi.mode(WIFI_STA);
  WiFi.disconnect(false);
  delay(150);
  int n = WiFi.scanNetworks(/*async=*/false, /*show_hidden=*/true);
  if (n <= 0) {
    Serial.printf("[wifi]   (no networks found, rc=%d)\n", n);
  } else {
    Serial.printf("[wifi]   %d network(s) in range:\n", n);
    for (int i = 0; i < n; i++) {
      Serial.printf("[wifi]   %-32s rssi=%4d ch=%2d%s\n", WiFi.SSID(i).c_str(),
                    WiFi.RSSI(i), WiFi.channel(i),
                    WiFi.SSID(i) == WIFI_SSID ? "   <-- target" : "");
    }
  }
  WiFi.scanDelete();
}

void connectWiFi() {
  if (WiFi.status() == WL_CONNECTED) return;
  Serial.printf("[wifi] connecting to \"%s\" ...\n", WIFI_SSID);
  WiFi.mode(WIFI_STA);
  WiFi.begin(WIFI_SSID, WIFI_PASS);
  uint32_t start = millis();
  while (WiFi.status() != WL_CONNECTED && millis() - start < WIFI_CONNECT_TIMEOUT) {
    delay(500);
    Serial.print('.');
  }
  Serial.println();
  if (WiFi.status() == WL_CONNECTED) {
    Serial.printf("[wifi] connected, ip=%s\n", WiFi.localIP().toString().c_str());
  } else {
    Serial.printf("[wifi] FAILED, status=%s\n", wifiStatusStr(WiFi.status()));
    scanNetworks();  // show what the radio can actually see
    Serial.println("[wifi] will retry");
  }
}

// POST {"room_id":..,"occupied":..} to /events. Returns HTTP status (<0 on error).
int sendHeartbeat(bool occupied) {
  if (WiFi.status() != WL_CONNECTED) {
    connectWiFi();
    if (WiFi.status() != WL_CONNECTED) return -1;
  }

  WiFiClientSecure client;
  client.setInsecure();  // skip cert validation — acceptable for this hackweek LAN use

  HTTPClient http;
  String url = String(API_BASE) + "/events";
  if (!http.begin(client, url)) {
    Serial.println("[http] begin failed");
    return -1;
  }
  http.addHeader("Content-Type", "application/json");
  http.addHeader("Authorization", String("Bearer ") + SENSOR_TOKEN);

  String body = String("{\"room_id\":\"") + SENSOR_ROOM_ID +
                "\",\"occupied\":" + (occupied ? "true" : "false") + "}";
  int code = http.POST(body);
  if (code > 0) {
    Serial.printf("[http] POST /events occupied=%d -> %d\n", occupied ? 1 : 0, code);
  } else {
    Serial.printf("[http] POST /events failed: %s\n", http.errorToString(code).c_str());
  }
  http.end();
  return code;
}

void setup() {
  Serial.begin(115200);
  delay(300);
  pinMode(RADAR_OUT_PIN, INPUT);
  WiFi.mode(WIFI_STA);
  WiFi.setAutoReconnect(true);

  Serial.println();
  Serial.println("=== Sentry Sonar :: sensor-node ===");
  Serial.printf("room=%s  api=%s  radar=GPIO%u\n", SENSOR_ROOM_ID, API_BASE, RADAR_OUT_PIN);
  if (strlen(SENSOR_TOKEN) == 0) {
    Serial.println("[warn] no auth token — reflash with flash-sensor.sh");
  }

  // Clean boot-time inventory of visible 2.4GHz networks (before any connect).
  scanNetworks();
  connectWiFi();

  bool occ = digitalRead(RADAR_OUT_PIN) == HIGH;
  reported = candidate = occ;
  candidateSince = millis();
}
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

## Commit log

2026-08-17 scaffold: volta + pnpm workspaces, api (hono/d1) + dashboard (vite/react) + firmware
2026-08-17 sensor-node: real firmware (radar -> wifi -> POST /events) + reusable flash script
    Reads LD2410C OUT pin, posts presence heartbeats to the API. flash-sensor.sh
    injects per-sensor room id + token (and prompts for WiFi password, never stored)
    via a gitignored config.gen.h. WiFi diagnostics + 2.4GHz-only constraint noted.
2026-08-17 hardware: 3D-printable sensor-node enclosure
    Parametric OpenSCAD box (internal 60x30x40mm) + drop-in lid, with wall/lid vent
    slits, a 5mm USB-C slit on one short side, and a 1mm thinned radar window in the
    lid. Rendered STLs for Bambu Studio + preview images.
    [sensor-node-box-body.stl, sensor-node-box-lid.stl, sensor-node-box.scad]
2026-08-17 busy-hours charts: hourly utilization buckets + stats-page chart
    API /rooms/:id/stats now returns per-hour occupied/observed buckets
    (reconstructed from the event log, split across hour boundaries). The stats page
    folds them into 24 local hour-of-day bins and renders an SVG bar chart.
    Also fixes a stale seed-rooms test (wednesday -> oida).
2026-08-17 observability: wire Sentry v11 (api + dashboard)
    API: withSentry() wraps the Worker (DSN via SENTRY_DSN secret; D1 auto-traced).
    Dashboard: Sentry.init + browserTracing + ErrorBoundary (frontend DSN in config,
    public by design; override via VITE_SENTRY_DSN).
2026-08-17 sentry: distributed tracing frontend -> api
    Add tracePropagationTargets (API origin) so the browser attaches
    sentry-trace/baggage to API calls, and allow those headers in the API CORS so
    the preflight passes. Frontend and API traces now connect.
2026-08-17 hardware: USB slit flush with floor, 7mm tall
    Move the USB-C opening to the very bottom (no gap above the floor) and enlarge it
    from 5mm to 7mm. Re-rendered body STL + preview.
    [sensor-node-box-body.stl, sensor-node-box.scad]
2026-08-17 hardware: thinner wall vent slits (2.5mm -> 1.6mm)
    [sensor-node-box-body.stl, sensor-node-box.scad]
2026-08-17 hardware: thinner wall vent slits (1.6mm -> 1.0mm)
    [sensor-node-box-body.stl, sensor-node-box.scad]
2026-08-17 hardware: thinner lid vent slits (2.5mm -> 1.0mm)
    [sensor-node-box-lid.stl, sensor-node-box.scad]
2026-08-17 make lid snap
    [sensor-node-box-body.stl, sensor-node-box-lid.stl, sensor-node-box.scad]
2026-08-18 update case
    [sensor-node-box-body.stl, sensor-node-box-lid.stl, sensor-node-box.scad]
2026-08-18 switch to 28d
